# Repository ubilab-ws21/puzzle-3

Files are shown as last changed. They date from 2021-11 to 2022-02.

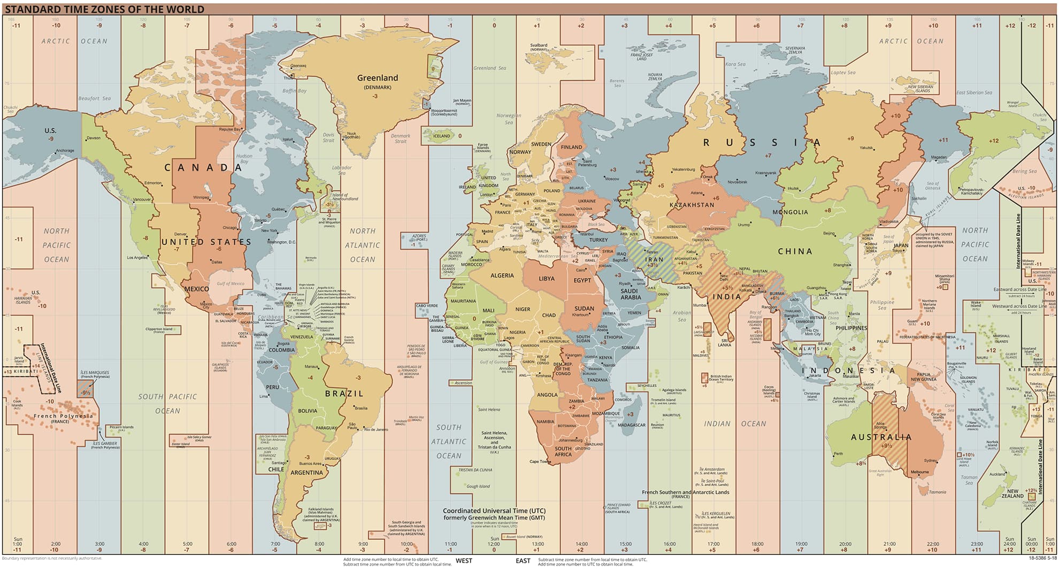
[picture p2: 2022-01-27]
designs/weltkarte-mit-zeitzonen-lg.jpg

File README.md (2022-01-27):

# Puzzle 3

## Contents
- [Puzzle overview](#puzzle-overview)
- [Repo Structure](#repo-structure)
- [Fitting the Puzzle into the story](#fitting-the-puzzle)
- [Puzzle description](#puzzle-description)
	- [Puzzle Part 1](#Puzzle-1)
	- [Puzzle Part 2](#Puzzle-2)
	- [Puzzle Part 3](#Puzzle-3)
- [MQTT Topics/Specification](#MQTT-Spec)
- [Documents](#documents)

## Puzzle overview

The central role of our puzzle plays a "radio".
The radio consists of a touchscreen display, a speaker, a module to play sound from an sd card, three encoders for tuning as well as one for the volume. The devices are all connected to a ESP32 WROOM Development kit. 
Final aim of the puzzle is to retrieve the so-called "green code" which is needed in a combination to restart the final server, i.e. to succeed in playining the Escape Room. 
It is to be discussed if the radio will maybe deliver more information, e.g. hints for the next puzzle (Morse-Code sound to open the server room door). 
The green code will eventually be displayed on the radio screen, once all the radio-related puzzles have been solved. The puzzles to be solved include the correct positioning of the three encoders which results in a change of the radio station.
The new channel also comes with a new radio display screen. Solving a word game now leads to the final green code. 

## Repo Structure

This repository is structured in the following way:
- datasheets contains all interesting datasheets
- designs contains eagle designs
- code contains the code
- notes cotains all notes from lectures and meetings

## Fitting the Puzzle into the story

The radio belongs to the hobby funker and former power distribution worker Ferdi. 
He has been fired a few years ago due to automatisation and digitalization of the distribution center. Ever since he has been fired, the work in the control room had been done autonomously. Ferdi has always predicted that the full autonoumous room can be dangerous in the future because nobody knows how to fix things if something goes wrong. 

## Puzzle Description 

### Puzzle Part 1 

There is an antenna hidden in the room. When the radio turns on, there is nothing but noise to hear. The players need to find the antenna and plug it into a socket one can find at the radio. This will trigger a button. Also, the correct positioning of the antenna makes a difference which is observed by an encoder insider the radio case. When both is fine, there will be no noise anymore and an emergency broadcast can be heard nicely.

### Puzzle Part 2
A world map is placed in the room. There are three colored pins placed on three diffeents countries pinned on the map. Meanwhile, the screen of the radio shows a three slider bars in the same colors, where the values of each bar can be changed with a correspondingly colored encoder.
Both the radio and the world map belong to the former control room worker, i.e. his name is printed on both the radio case and the world map.
The emergency broadcast plays repeatedly. 
The players must look at the pins on the map, extract the difference of the locations to the greenwich mean time (=delta) and turn the correspondingly colored encoders so that the sliding bars have the deltas as values. When this is done, the Emergency broadcast stops, and instead the voice of the former control room worker, a hobby radio operator, arises. Also the screen changed. The puzzle is solved.

### Puzzle Part 3
In the recording, the former control room worker repeatedly says that he has forseen this and that going away from manual control to autonoumously controlled distribution was a bad choice. 
The screen shows a word puzzle, where it is not clear yet how it looks exactly. From the voice from the radio guy it becomes clear how to solve the puzzle.
After the puzzle was solved, the screen changes again and shows the code which is needed for the next puzzle of the next group (code for opening the door via light bulbs)

## MQTT Topics/Specification

| Topic | Description | Payload | Reset-Value | Subscriber | Publisher |
| :--:	| :---: | :---:| :---: |:---: | :---:|
| 3/gamecontrol| Control the radio: which puzzle state is currently in play | Enum(Gamecontrol) | idle | radio, operator | radio, operator | 
| 3/antenna/orientation | gives information if the angle of the antenna correct | boolean | false | operator | radio |
| 3/map/knob1 | gives information whether knob1 is in correct position | boolean | false | operator | radio |
| 3/map/knob2 | gives information whether knob2 is in correct position | boolean | false | operator | radio |
| 3/map/knob3 | gives information whether knob3 is in correct position | boolean | false | operator | radio |
| 3/touchgame/trialCount | gives information about the trails the group already had | int | 0 | operator | radio |
| 3/touchgame/displayTime | the game can either be set in easy or hard mode | boolean | false | radio | operator |

3/gamecontrol maybe splitted to received and sended topic. For now we wait for feedback by the operator

| Enum(gameControl) | Description | Subscriber | Publisher |
| :---: | :---: | :---: | :---: |
| idle | Radiopuzzle is waiting in idle mode to be started by operator | radio | operator |
| antenna | antenna game is started by operator | radio | operator |
| antennaFinished | antenna game is finished | operator | radio |
| map | map game is started by operator | radio | operator |
| mapFinished | map game is finished | operator | radio |
| touchgame | touchgame is started by operator | radio | operator |
| touchgameFinished | touchgame is finished | operator | radio |
| finished | radio game is finished | operator | radio |

| int(trailCount) | Description |
| :---: | :---: |
| ++ | everytime the game is failed, the trialcounter is increased |

#Topic: 3/gamecontrol

Description: Control the radio: which puzzle state is currently in play

Payload: Enum(Gamecontrol)

Reset-Value: Idle

Enum Values:

# Idle: Radio puzzle is waiting in Idle mode to be started
- Publisher: Operator: set the third puzzle in idle mode
- Subscriber: Radio: receive to stay in idle mode

- antenna: antenna game is started
	Operator: start the first part of the puzzle
	radio: receive to start the puzzle with antenna game
- antennaFinished: antenna game is finished
	Operator: receive updates on the gamestatus
	radio: update once the game is finished

- map: map game is played
	Operator: start the second part of the puzzle
	radio: receive to start the second part of the puzzle
- mapFinished: map game is finished
	Operator: receive updates on the gamestatus
	radio: update once the game is finished

- touchgame: touchgame is played
	Operator: start the third part of the puzzle
	radio: receive to start the third part of the puzzle
- touchgameFinished: touchgame is finished
	Operator: receive updates on the game status
	radio: update once the game is finished

- finished: puzzle 3 is solved
	Operator: set the third puzzle in finished mode
	radio: receive to get in finished mode

<!--Topic: 3/antenna/plugStatus

#Description: gives information about the antenna

% Payload: boolean

Reset-Value: false
	Radio: update if antenna is plugged in
	Operator: receive updates on the antenna-->
	
Topic: 3/antenna/orientation

Description: gives information about the antenna orientation, should the operator know about the randomisation of the required postion?

Payload: int[0-23] or boolean
	Radio: update if antenna is set up in the correct direction
	Operator: receive updates on the antenna orientation

Topic: 3/map/knob1

Description: Control/Check the first knob

Playload: boolean

Reset-Value: false
	Radio: update if the the first knob/color reaches/leaves the correct postion
	Operator: receive updates on the first knob

Topic: 3/map/knob2

Description: Control/Check the second knob

Playload: boolean

Reset-Value: false
	Radio: update if the the second knob/color reaches/leaves the correct postion
	Operator: receive updates on the second knob

Topic: 3/map/knob3

Description: Control/Check the third knob

Playload: boolean

Reset-Value: false
	Radio: update if the the third knob/color reaches/leaves the correct postion
	Operator: receive updates on the third knob

Topic: 3/touchgame/trialCount

Description: Sends the number of trials to the operator 

Payload: int

Reset-Value is 0
	Radio: Update the trial number after each failed attempt
	Operator: receive updates on the failed attempts
	
Topic: 3/touchgame/displayTime

Description: Operator sets the time to easy or hard mode

Payload: boolean

Reset-Value: false
	Radio: receive updates on mode setting
	Operator: set mode for puzzle

Description: needs some discussion what should be updated to the operator

## Documents
The datasheets can be found in the datasheets directory

## Notes
The board with the ICs, placed on the bottom of the radio case inside, should be 9cm x 13cm long.
Software game: We only have one rectangle. By placing the blue rectangle on a letter and touching it, the rectangle and the letter will go to the next free location in the password space.

Next Tasks - 23.01
- Driver Board an case anbringen
- MQTT auf ESP32 fertig implementieren

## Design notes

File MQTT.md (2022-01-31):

The MQQT-Specification for Puzzle 3:

| Topic | Description | Payload | Reset-Value | Subscriber | Publisher |
| :--:	| :---: | :---:| :---: |:---: | :---:|
| 3/gamecontrol/antenna| Control the radio: start first puzzle & receive updates on it | on & off, inactive, active & solved | off | radio, operator | radio, operator | 
| 3/gamecontrol/map | Control the radio: start the second puzzle & receive updates on it | on & off, inactive, active & solved | off | operator, radio | radio, operator |
| 3/gamecontrol/touchgame | Control the radio: start the third puzzle & receive updates on it | on & off, inactive, active & solved | off | operator, radio | radio, operator |
| 3/audiocontrol/roomsolved | Control the radio: play final message when the room is solved | on & off | off | radio | operator |

We reduced the amount of MQTT-Topics since the hint-system is controlled by us directly: Therefore it is not required to send all informations to the operator, which are not really helpful in terms of gamecontrol.

MQTT-Topics for the hint-system
| Topic | Description | Payload | Reset-Value | Subscriber | Publisher |
| :--:	| :---: | :---:| :---: |:---: | :---:|
| game/puzzle3/antenna | Hint-System: Unlock the hint for the first game | active_1 & inactive | inactive | hint-system | radio |
| game/puzzle3/map | Hint-System: Unlock the hints for the second game | active_1, active_2 & inactive | inactive | hint-system | radio |
| game/puzzle3/touchgame | Hint-System: Unlock the hints for the third game | active_1, active_2, active_3, active_4 & inactive | inactive | hint-system | radio |

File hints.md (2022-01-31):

### Hints to be display for Puzzle 3 including the MQTT-Spec

## Game 1: Antenna
Hint 1: What do you do if a radio does have a bad connection?
MQTT-Message: game/puzzle3/antenna : {"method": "trigger", "state": "active_1"}

## Game 2: Map
Hint 1: The room operator usually spend his holiday at three locations
MQTT-Message: game/puzzle3/map : {"method": "trigger", "state": "active_1"}

Hint 2: These locations are in different time zones
MQTT-Message: game/puzzle3/map : {"method": "trigger", "state": "active_2"}

## Game 3: Touchgame
Hint 1: Touch the letters to build a word.
MQTT-Message: game/puzzle3/touchgame : {"method": "trigger", "state": "active_1"}

Hint 2: Listen carefully.
MQTT-Message: game/puzzle3/touchgame : {"method": "trigger", "state": "active_2"}

Hint 3: Not automatic.
MQTT-Message: game/puzzle3/touchgame : {"method": "trigger", "state": "active_3"}

Hint 4: Manual.
MQTT-Message: game/puzzle3/touchgame : {"method": "trigger", "state": "active_4"}

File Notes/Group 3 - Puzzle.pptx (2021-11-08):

## Group 3

Puzzle

## Puzzle 3 Idea 2

- Radio plays news/emergency broadcast
  - Starts when emergency electricity is back on (or by solving another puzzle)
  - A sound/jingle is playing in the background or as a intro – repeated
  - Sound code is key to ??? – safe/door/etc. (buttons play same tone/sound)
- A received code will lead to a hidden radio station – every other station will play the standard
- Unknown person (aluhat guy/hobby radio operator) tells crazy story that leads to information for next puzzle

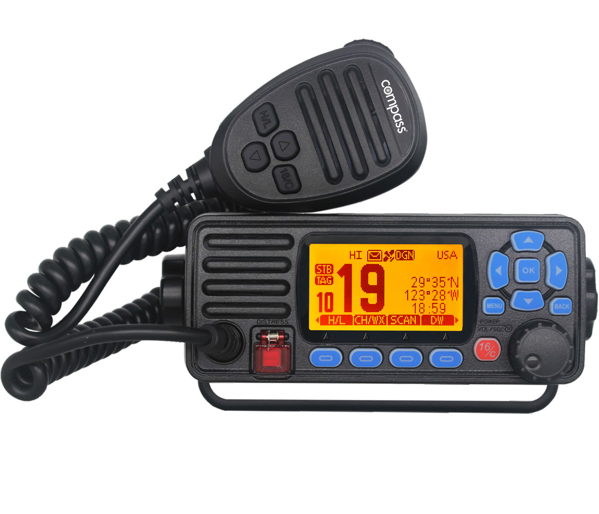
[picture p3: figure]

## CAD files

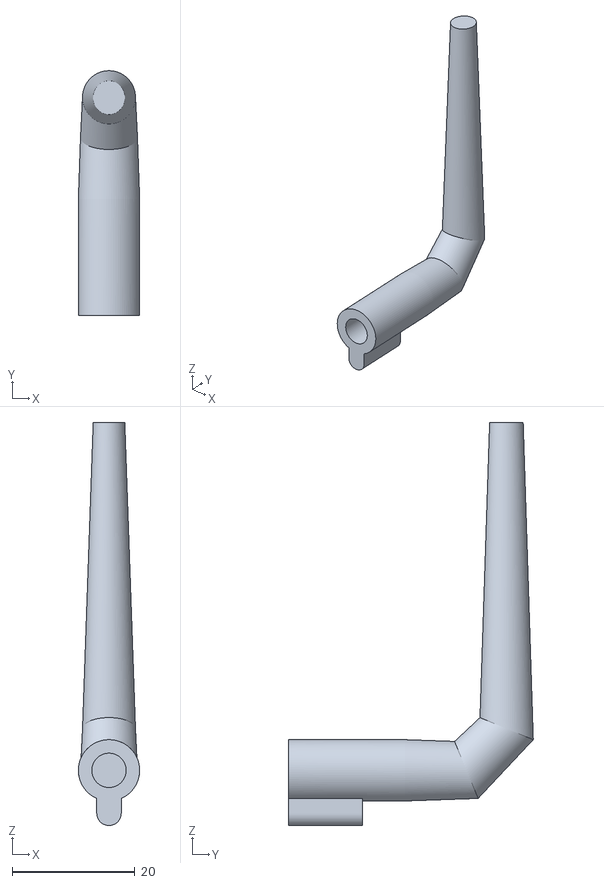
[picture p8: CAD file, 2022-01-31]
designs/3D_Manufactoring/Antenna.stl
10.00 x 39.9 x 65.7

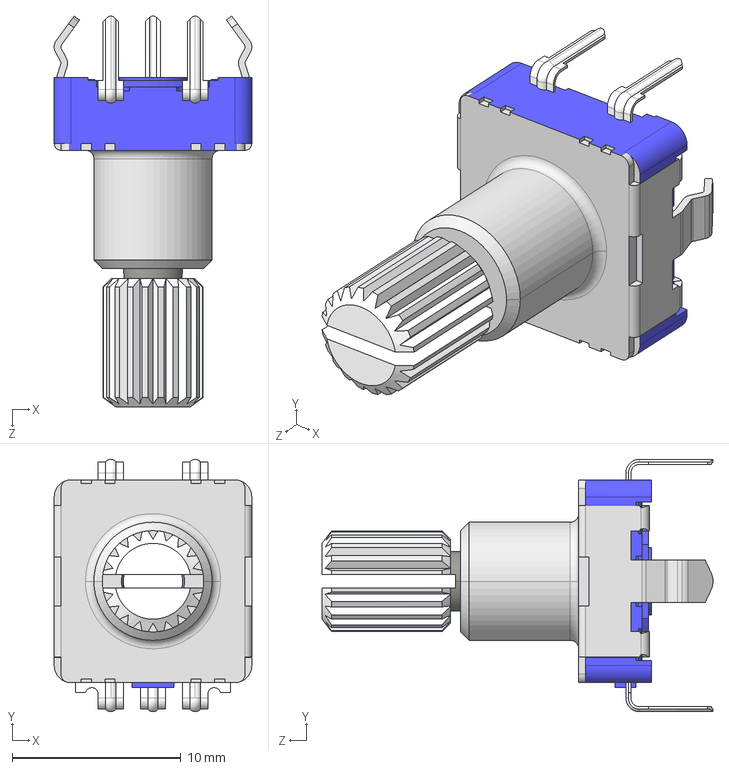
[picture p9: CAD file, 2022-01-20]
designs/3D_Modeling/ec11_rotarary_encoder/EC11 Rotary Encoder Dode Switch-15mm .STEP
11.7 x 15.0 x 23.2 mm

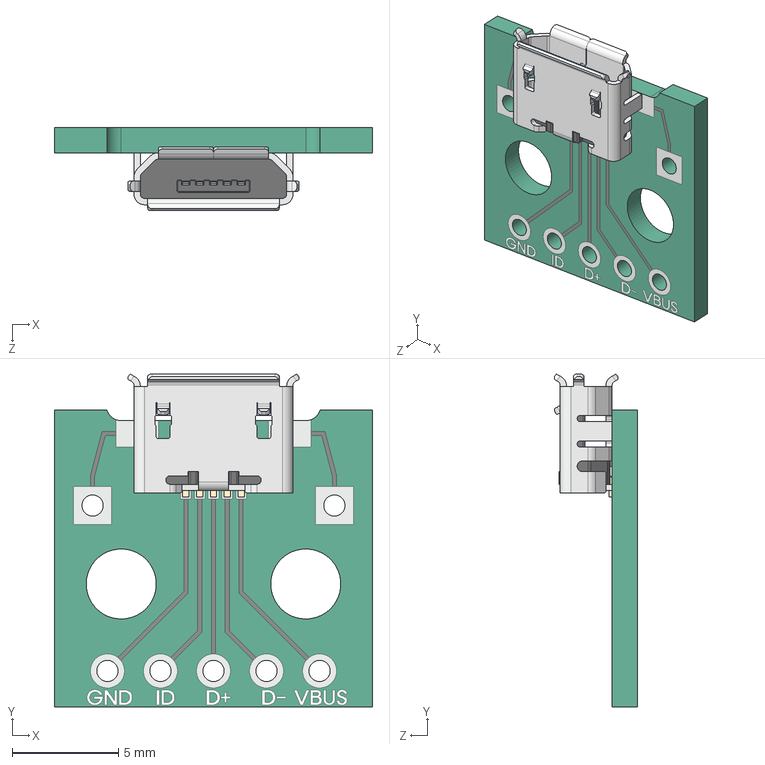
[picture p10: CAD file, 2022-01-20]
designs/3D_Modeling/microusb_5pin/REAL-Usb 5pin Board.STEP
15.0 x 15.7 x 3.92 mm

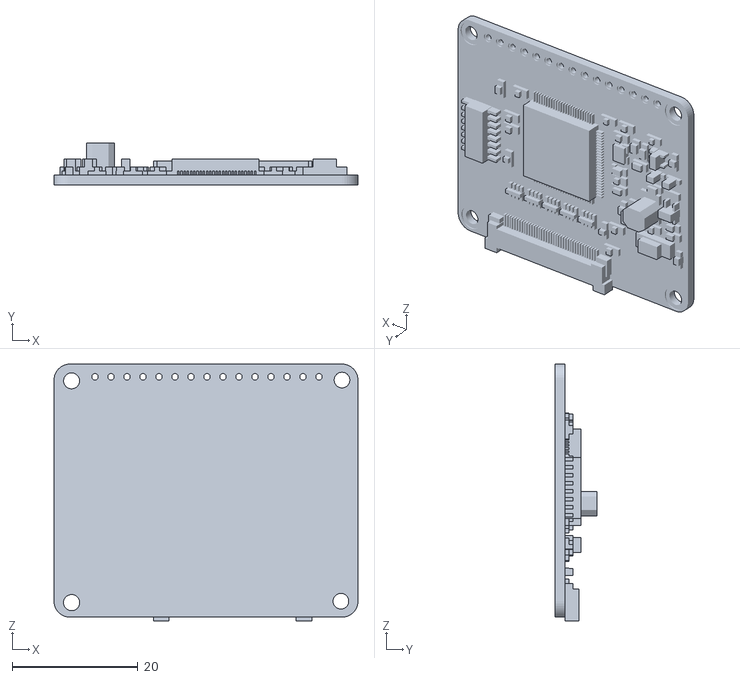
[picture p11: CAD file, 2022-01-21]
designs/3D_Modeling/RA8875 Driver Board.STL
48.3 x 6.68 x 40.8

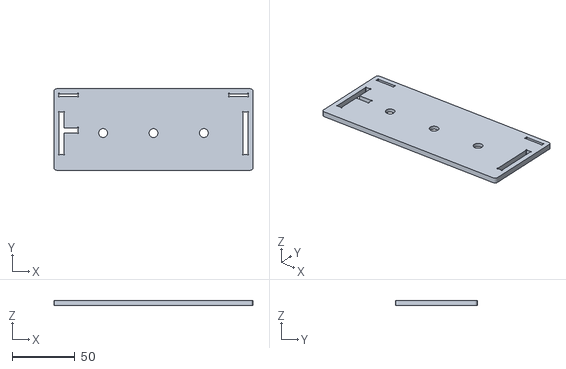
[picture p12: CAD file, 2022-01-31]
designs/3D_Manufactoring/topPlate_3DPrint.stl
158.0 x 64.7 x 4.00

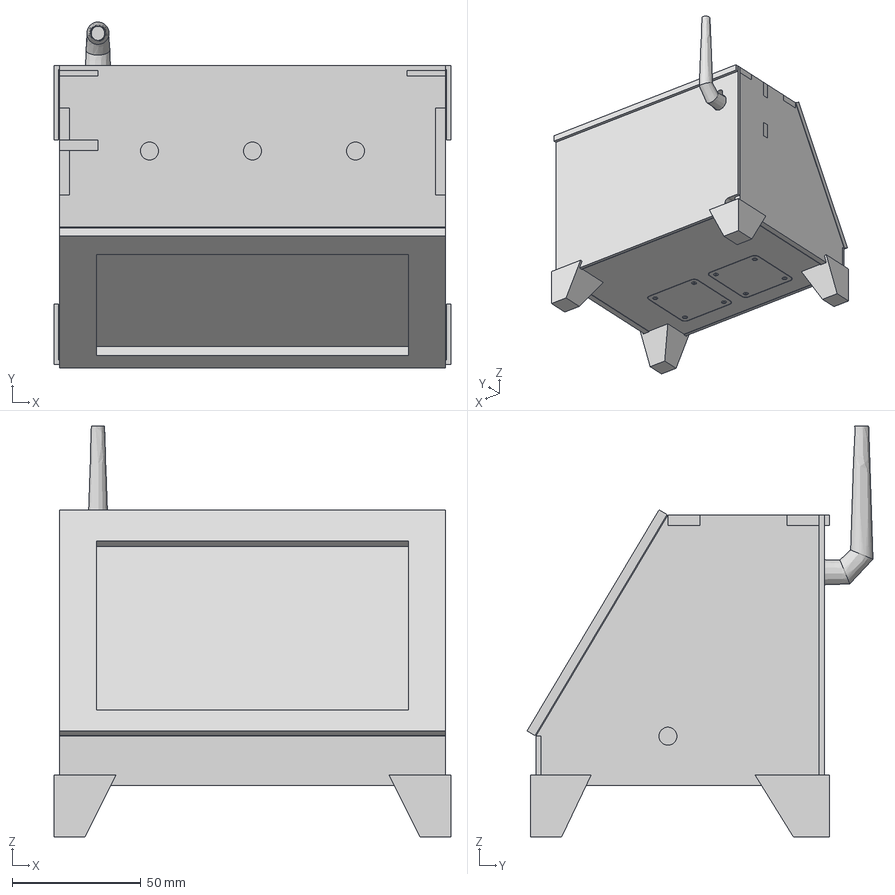
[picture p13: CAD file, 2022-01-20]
designs/3D_Modeling/Radio.step
154.0 x 134.3 x 159.6 mm
Speaker v3
Antenna_3D
EC11 Rotary Encoder Dode Switch-15mm
groundPlate_3D
rightPlate_laser
leftPlate_laser
frontPlate_CNC
backPlate_CNC
topPlate_laser
Component_Display
REAL-Usb 5pin Board

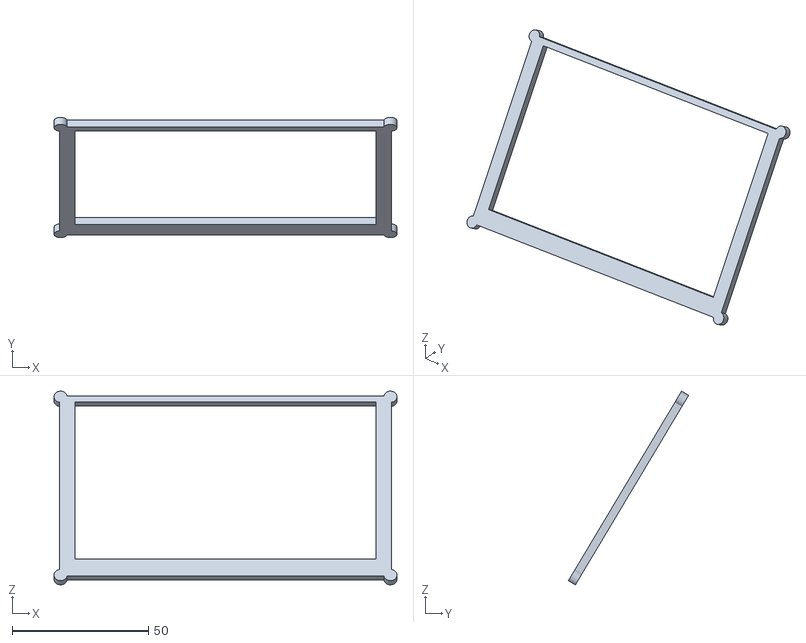
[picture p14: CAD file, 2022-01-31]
designs/3D_Manufactoring/DisplayHousingTop.stl
126.0 x 44.2 x 71.2

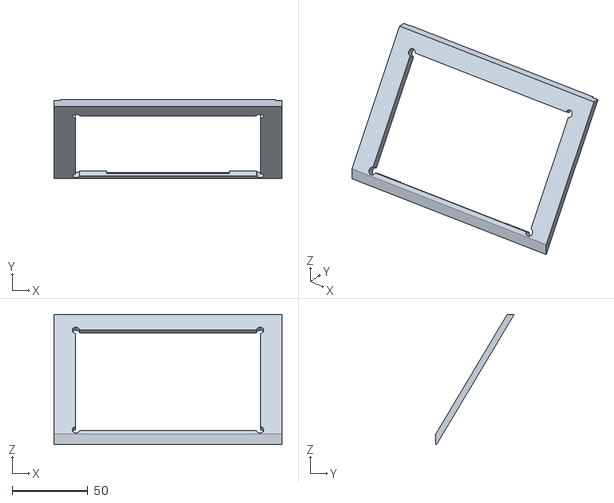
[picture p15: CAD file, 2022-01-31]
designs/3D_Manufactoring/DisplayHousingButtomTEST.stl
150.0 x 51.7 x 85.9

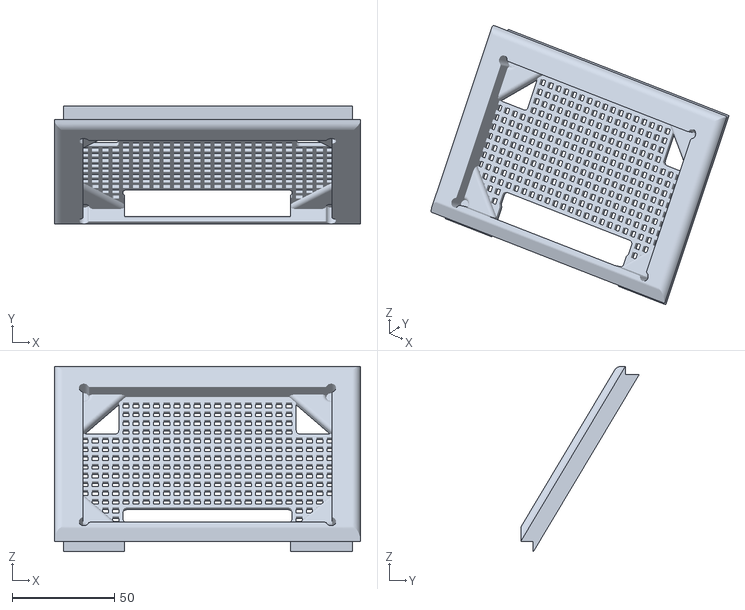
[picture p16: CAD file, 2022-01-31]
designs/3D_Manufactoring/DisplayHousingButtom.stl
150.0 x 58.1 x 90.9

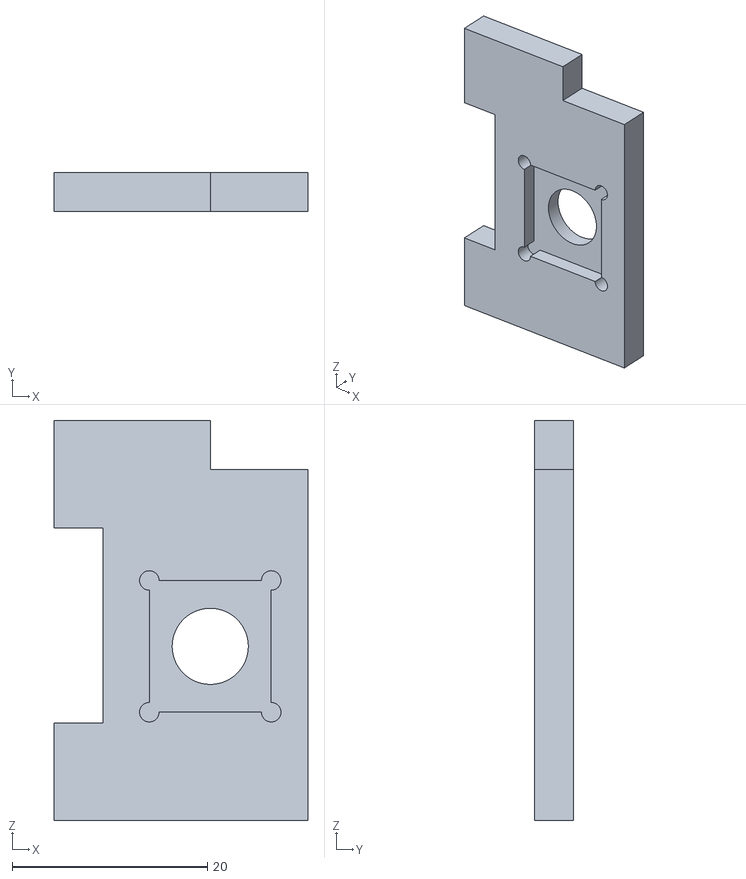
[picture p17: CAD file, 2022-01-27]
designs/3D_Manufactoring/antennaSupport_3DprintV3.stl
26.0 x 4.00 x 41.0

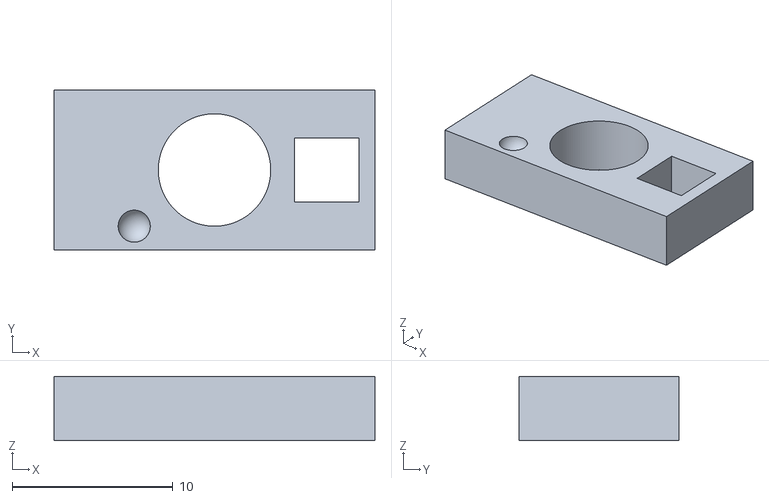
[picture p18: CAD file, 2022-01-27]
designs/3D_Manufactoring/smallTestPrint.stl
20.0 x 10.0 x 4.00

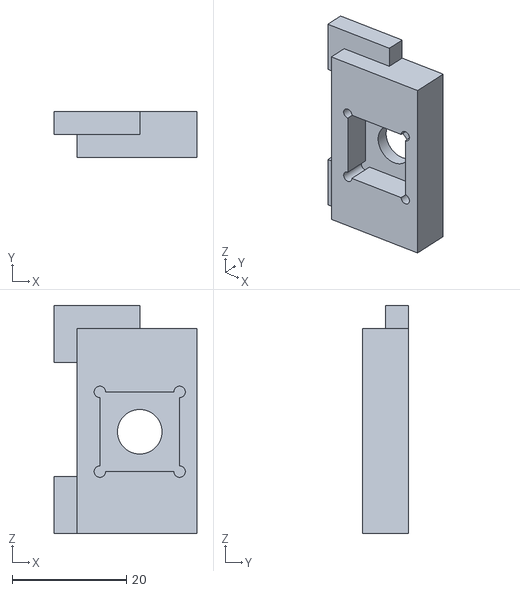
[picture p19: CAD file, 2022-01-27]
designs/3D_Manufactoring/antennaSupport_3Dprint.stl
25.0 x 8.00 x 40.0

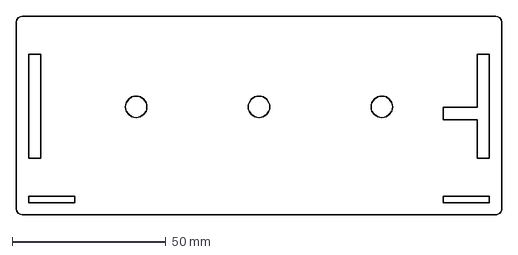
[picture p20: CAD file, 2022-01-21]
designs/3D_Manufactoring/topPlate.dxf
158.0 x 64.7 mm

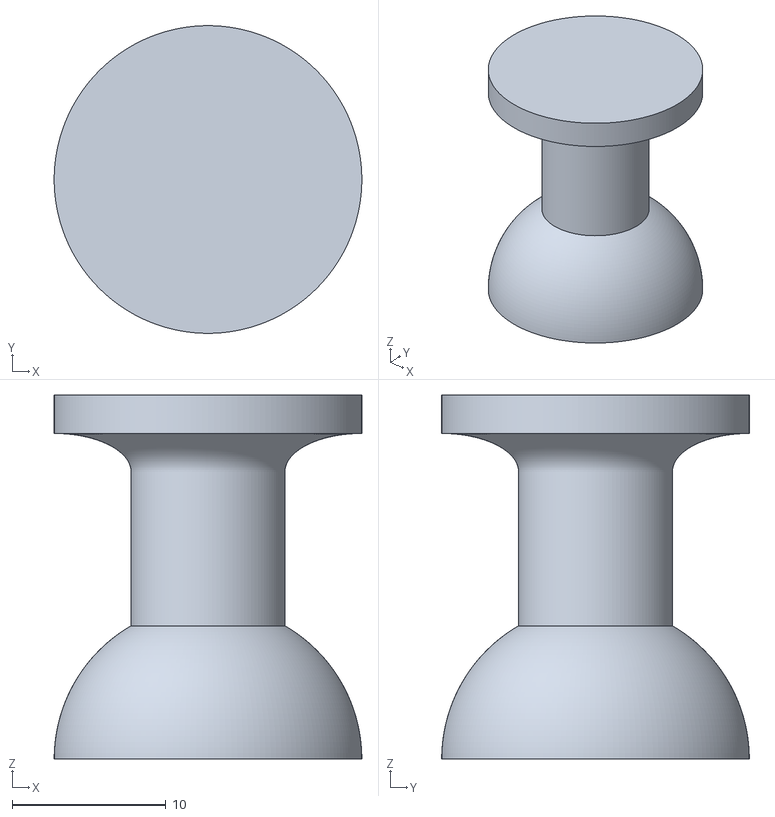
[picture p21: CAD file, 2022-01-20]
designs/3D_Manufactoring/EncoderPinHead.stl
20.0 x 20.0 x 23.7

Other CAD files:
designs/3D_Manufactoring/leftPlate.dxf
designs/3D_Manufactoring/groundPlate.stl
designs/3D_Manufactoring/DisplayCircuitMount.stl
designs/3D_Manufactoring/antennaSupport.dxf
designs/3D_Manufactoring/antennaSupport_3DprintV2.stl
designs/3D_Manufactoring/antennaSupport_3Dprint_v1.stl
designs/3D_Manufactoring/rightPlate.dxf
designs/3D_Modeling/microusb_5pin/REAL-Usb 5pin Board.SLDPRT
designs/3D_Modeling/microusb_5pin/REAL-Usb 5pin Board.x_t

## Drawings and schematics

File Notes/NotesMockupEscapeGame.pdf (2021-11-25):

Notes | Tiah | Play | Escape Roon | 25.1120µV
- | Radio will | provider | 2 codes ?

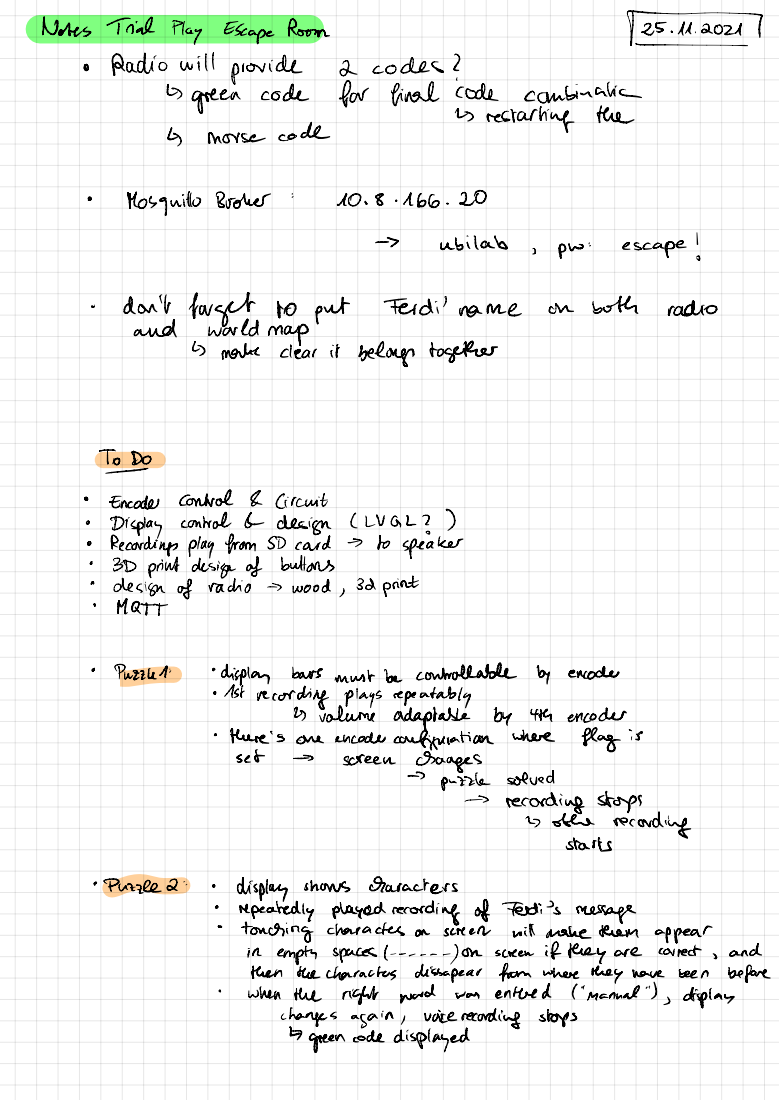
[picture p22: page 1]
green; code; for; final; Code; combination; resrartinf; the; Morsecode; Mosquito; Bücher; ubilab; escape !; don't; fwgct; put; Ferdi ' name; both; radio; and; world map ↳; make; Hear it; belong; together; Toto; Encoder; Conhrol; Circuit; Display; antrat &; design; LVGL; Recordings; play from SD; card; speaker •; print; design of; buttons; wood; print •; MQTT; Puzzle1:; display; bavs.mustbecontrollabll.by; encoder; recording; plays repeatablg; volume; adaptable; 4th encoder; there's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

green code displaced

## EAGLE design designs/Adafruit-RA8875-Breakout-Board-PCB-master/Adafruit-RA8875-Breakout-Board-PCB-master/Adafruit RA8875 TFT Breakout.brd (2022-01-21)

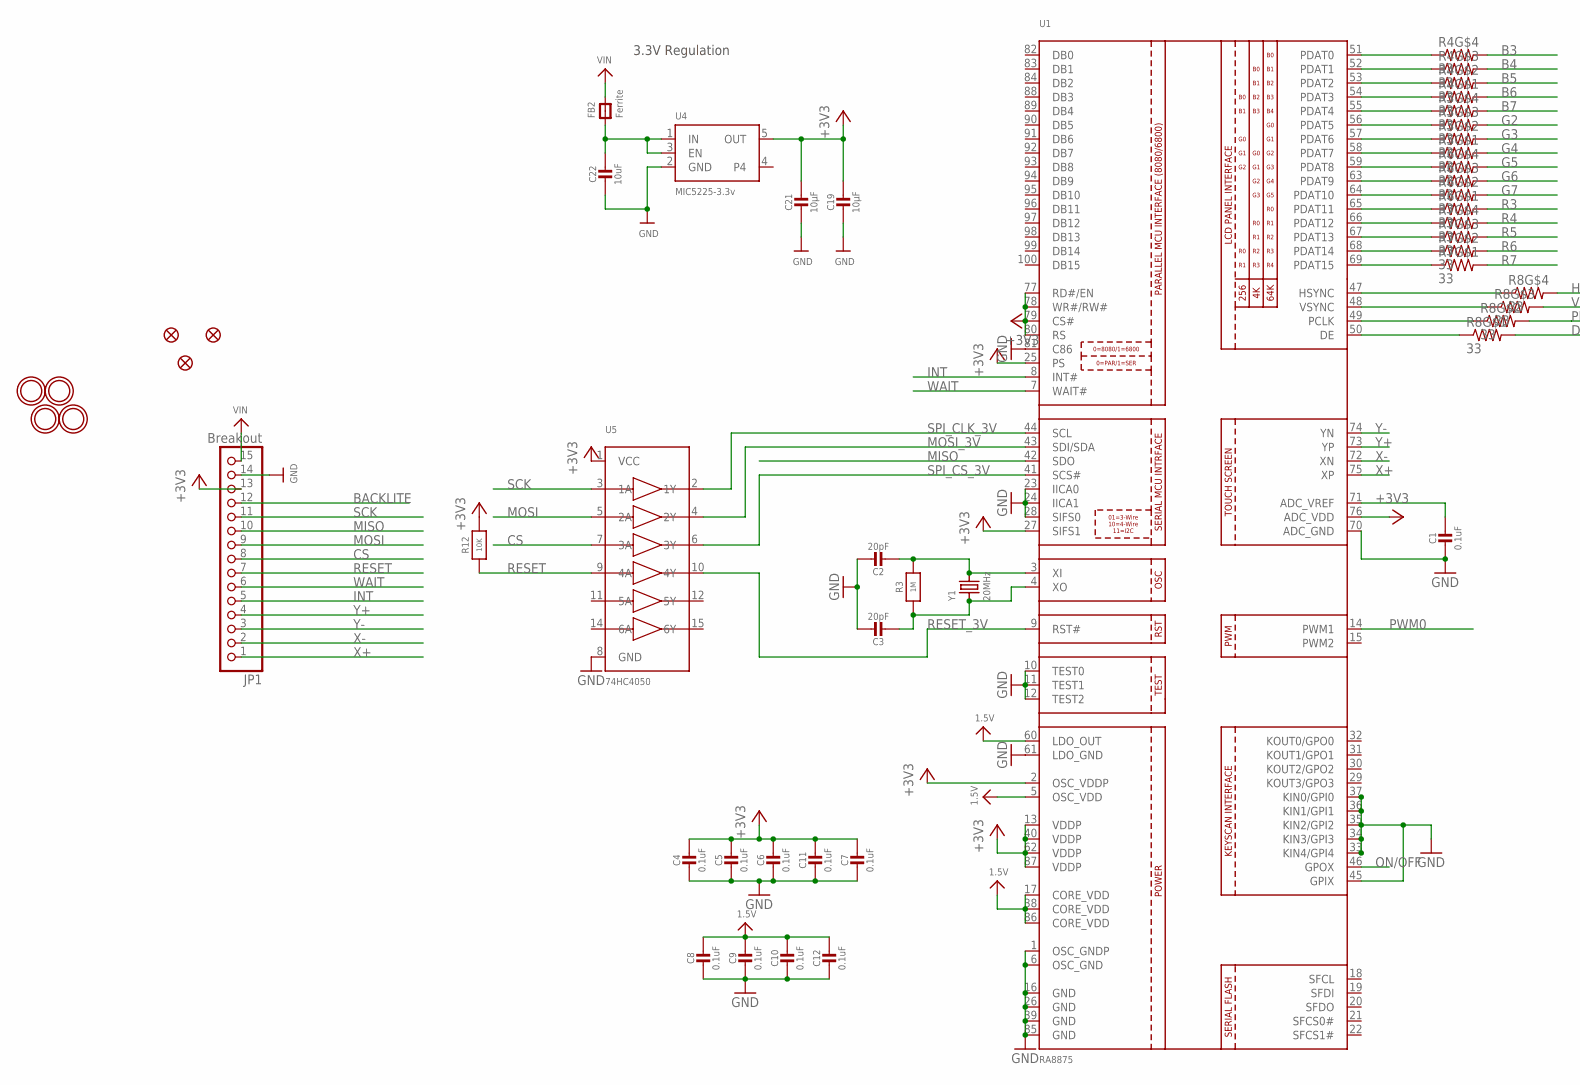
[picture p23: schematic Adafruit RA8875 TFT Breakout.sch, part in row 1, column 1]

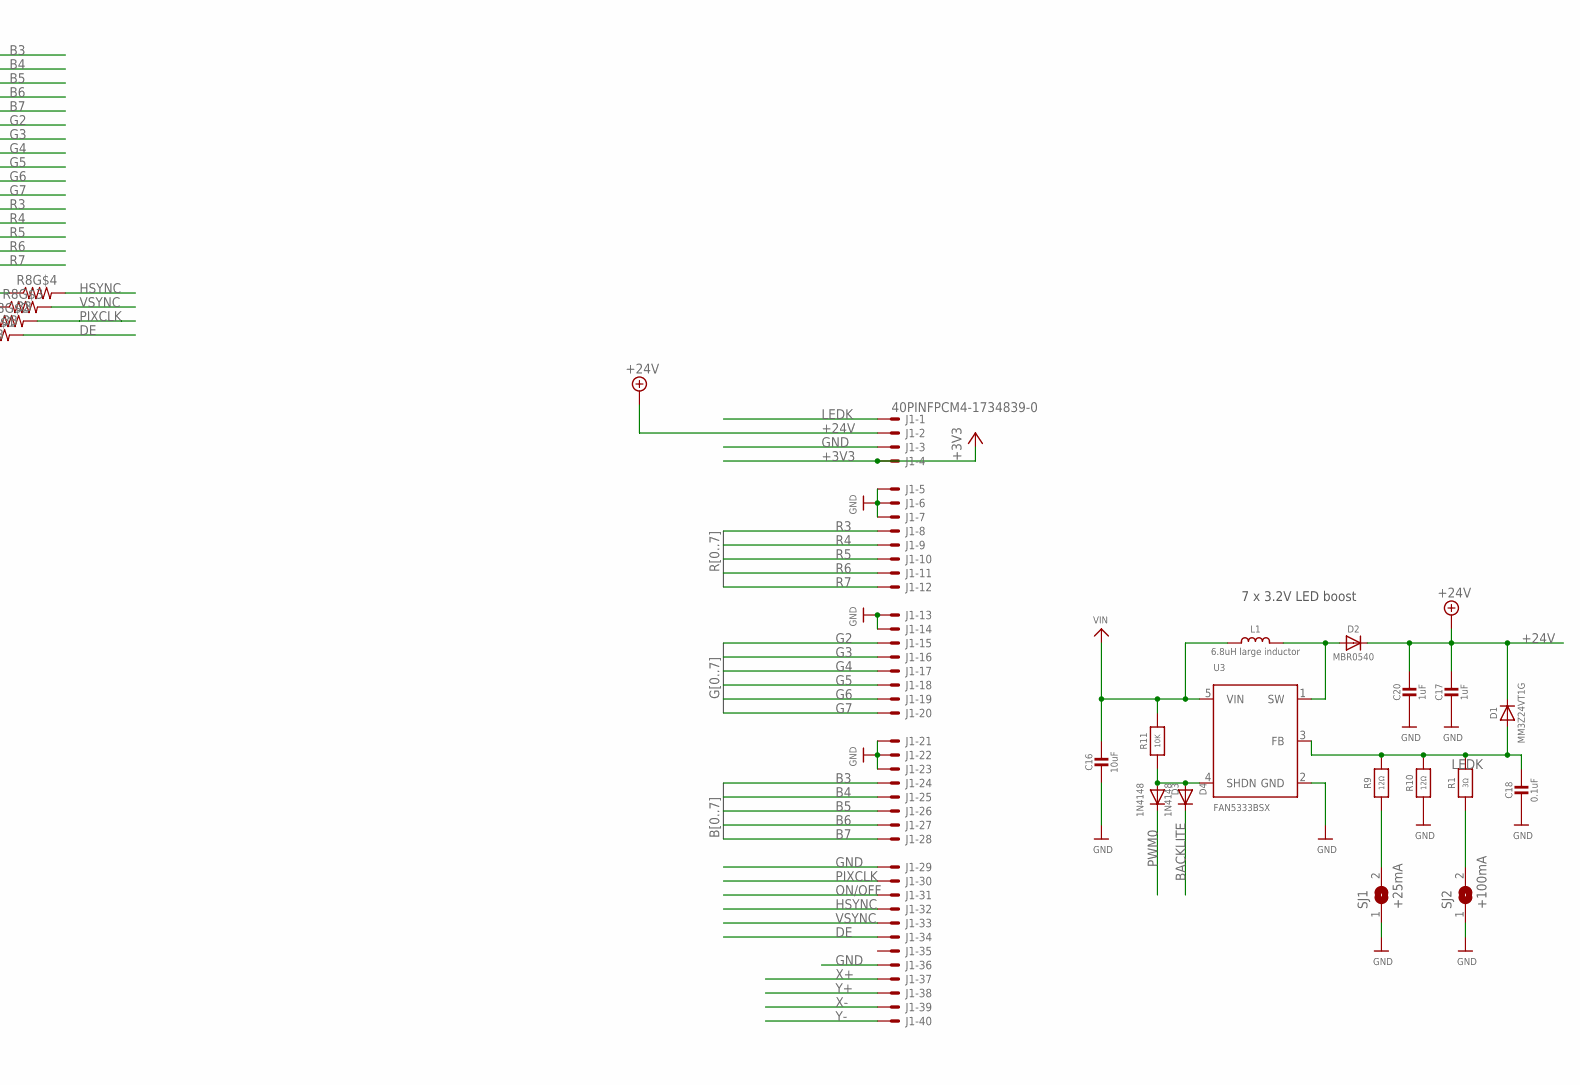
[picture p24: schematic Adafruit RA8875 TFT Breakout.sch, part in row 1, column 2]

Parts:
C1, C4, C5, C6, C7, C8, C9, C10, C11, C12: 0.1uF; 0805-NO
C2, C3: 20pF; 0805-NO
C16, C22: 10uF; _0805MP
C17, C20: 1uF; _0805MP
C18: 0.1uF; _0805MP
C19, C21: 10µF; _0805MP
D1: MM3Z24VT1G; SMADIODE
D2: MBR0540; SOD-123
D3, D4: 1N4148; SOD-323F
FB2: Ferrite; _0805MP
FID1, FID2, FID3: FIDUCIAL""; FIDUCIAL_1MM
J1: 40PINFPCM4-1734839-0; 4-1734839-0
JP1: Breakout; 1X15-CB
L1: 6.8uH large inductor; INDUCTOR_5X5MM_NR5040_NOTHERMALS
R1: 3Ω; _0805MP
R3: 1M; 0805-NO
R4, R5, R6, R7, R8: 33; RESPACK_4X0603
R9, R10: 12Ω; _0805MP
R11: 10K; _0805MP
R12: 10K; 0805-NO
SJ1: +25mA; SOLDERJUMPER_ARROW_NOPASTE
SJ2: +100mA; SOLDERJUMPER_ARROW_NOPASTE
U1: RA8875; LQFP100
U3: FAN5333BSX; SOT23-5@1
U4: MIC5225-3.3v; SOT23-5
U5: 74HC4050; SOIC16
U$21, U$22, U$23, U$24: MOUNTINGHOLE2.5; MOUNTINGHOLE_2.5_PLATED
Y1: 20MHz; CRYSTAL_3.2X2.5

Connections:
1.5V: C8.1, C9.1, C10.1, C12.1, U1.5 (OSC_VDD), U1.17 (CORE_VDD), U1.38 (CORE_VDD), U1.60 (LDO_OUT), U1.86 (CORE_VDD)
+3V3: C4.1, C5.1, C6.1, C7.1, C11.1, C19.1, C21.1, J1.4 (MS), JP1.13, R12.2, U1.2 (OSC_VDDP), U1.13 (VDDP), U1.25 (PS), U1.27 (SIFS1), U1.40 (VDDP), U1.62 (VDDP), U1.76 (ADC_VDD), U1.77 (RD#/EN), U1.78 (WR#/RW#), U1.79 (CS#), U1.80 (RS), U1.87 (VDDP), U4.5 (OUT), U5.1 (VCC)
+24V: C17.1, C20.1, D1.C, D2.C, J1.2 (MS)
B3: J1.24 (MS), R4.5 (2)
B4: J1.25 (MS), R4.6 (2)
B5: J1.26 (MS), R4.7 (2)
B6: J1.27 (MS), R4.8 (2)
B7: J1.28 (MS), R5.5 (2)
BACKLITE: D4.C, JP1.12
CS: JP1.8, U5.7 (3A)
DE: J1.34 (MS), R8.8 (2)
G2: J1.15 (MS), R5.6 (2)
G3: J1.16 (MS), R5.7 (2)
G4: J1.17 (MS), R5.8 (2)
G5: J1.18 (MS), R6.5 (2)
G6: J1.19 (MS), R6.6 (2)
G7: J1.20 (MS), R6.7 (2)
GND: C1.2, C2.1, C3.1, C4.2, C5.2, C6.2, C7.2, C8.2, C9.2, C10.2, C11.2, C12.2, C16.2, C17.2, C18.2, C19.2, C20.2, C21.2, C22.2, J1.3 (MS), J1.5 (MS), J1.6 (MS), J1.7 (MS), J1.13 (MS), J1.14 (MS), J1.21 (MS), J1.22 (MS), J1.23 (MS), J1.29 (MS), J1.36 (MS), JP1.14, R10.1, SJ1.1, SJ2.1, U1.1 (OSC_GNDP), U1.6 (OSC_GND), U1.10 (TEST0), U1.11 (TEST1), U1.12 (TEST2), U1.16 (GND), U1.23 (IICA0), U1.24 (IICA1), U1.26 (GND), U1.28 (SIFS0), U1.33 (KIN4/GPI4), U1.34 (KIN3/GPI3), U1.35 (KIN2/GPI2), U1.36 (KIN1/GPI1), U1.37 (KIN0/GPI0), U1.39 (GND), U1.45 (GPIX), U1.61 (LDO_GND), U1.70 (ADC_GND), U1.81 (C86), U1.85 (GND), U3.2 (GND), U4.2 (GND), U5.8 (GND)
HSYNC: J1.32 (MS), R8.5 (2)
INT: JP1.5, U1.8 (INT#)
LEDK: C18.1, D1.A, J1.1 (MSV), R1.2, R9.2, R10.2, U3.3 (FB)
MISO: JP1.10, U1.42 (SDO)
MOSI: JP1.9, U5.5 (2A)
MOSI_3V: U1.43 (SDI/SDA), U5.4 (2Y)
unnamed: D2.A, L1.P$2 (2), U3.1 (SW)
unnamed: C2.2, R3.2, U1.3 (XI), Y1.2
unnamed: C1.1, U1.71 (ADC_VREF)
unnamed: R4.4 (1), U1.51 (PDAT0)
unnamed: R4.3 (1), U1.52 (PDAT1)
unnamed: R4.2 (1), U1.53 (PDAT2)
unnamed: R4.1, U1.54 (PDAT3)
unnamed: R5.4 (1), U1.55 (PDAT4)
unnamed: R5.3 (1), U1.56 (PDAT5)
unnamed: R5.2 (1), U1.57 (PDAT6)
unnamed: R5.1, U1.58 (PDAT7)
unnamed: R6.4 (1), U1.59 (PDAT8)
unnamed: R6.3 (1), U1.63 (PDAT9)
unnamed: R6.2 (1), U1.64 (PDAT10)
unnamed: R6.1, U1.65 (PDAT11)
unnamed: R7.4 (1), U1.66 (PDAT12)
unnamed: R7.3 (1), U1.67 (PDAT13)
unnamed: R7.2 (1), U1.68 (PDAT14)
unnamed: R7.1, U1.69 (PDAT15)
unnamed: R8.1, U1.50 (DE)
unnamed: R8.2 (1), U1.49 (PCLK)
unnamed: R8.3 (1), U1.48 (VSYNC)
unnamed: R8.4 (1), U1.47 (HSYNC)
unnamed: R9.1, SJ1.2
unnamed: C22.1, FB2.1, U4.1 (IN), U4.3 (EN)
unnamed: R1.1, SJ2.2
unnamed: C3.2, R3.1, U1.4 (XO), Y1.1
ON/OFF: J1.31 (MS), U1.46 (GPOX)
PIXCLK: J1.30 (MS), R8.7 (2)
PWM0: D3.C, U1.14 (PWM1)
R3: J1.8 (MS), R6.8 (2)
R4: J1.9 (MS), R7.5 (2)
R5: J1.10 (MS), R7.6 (2)
R6: J1.11 (MS), R7.7 (2)
R7: J1.12 (MS), R7.8 (2)
RESET: JP1.7, R12.1, U5.9 (4A)
RESET_3V: U1.9 (RST#), U5.10 (4Y)
SCK: JP1.11, U5.3 (1A)
SHDN: D3.A, D4.A, R11.1, U3.4 (SHDN)
SPI_CLK_3V: U1.44 (SCL), U5.2 (1Y)
SPI_CS_3V: U1.41 (SCS#), U5.6 (3Y)
VIN: C16.1, FB2.2, JP1.15, L1.P$1 (1), R11.2, U3.5 (VIN)
VSYNC: J1.33 (MS), R8.6 (2)
WAIT: JP1.6, U1.7 (WAIT#)
X+: J1.37 (MS), JP1.1, U1.75 (XP)
X-: J1.39 (MS), JP1.2, U1.72 (XN)
Y+: J1.38 (MS), JP1.4, U1.73 (YP)
Y-: J1.40 (MS), JP1.3, U1.74 (YN)

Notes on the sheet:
7 x 3.2V LED boost
3.3V Regulation

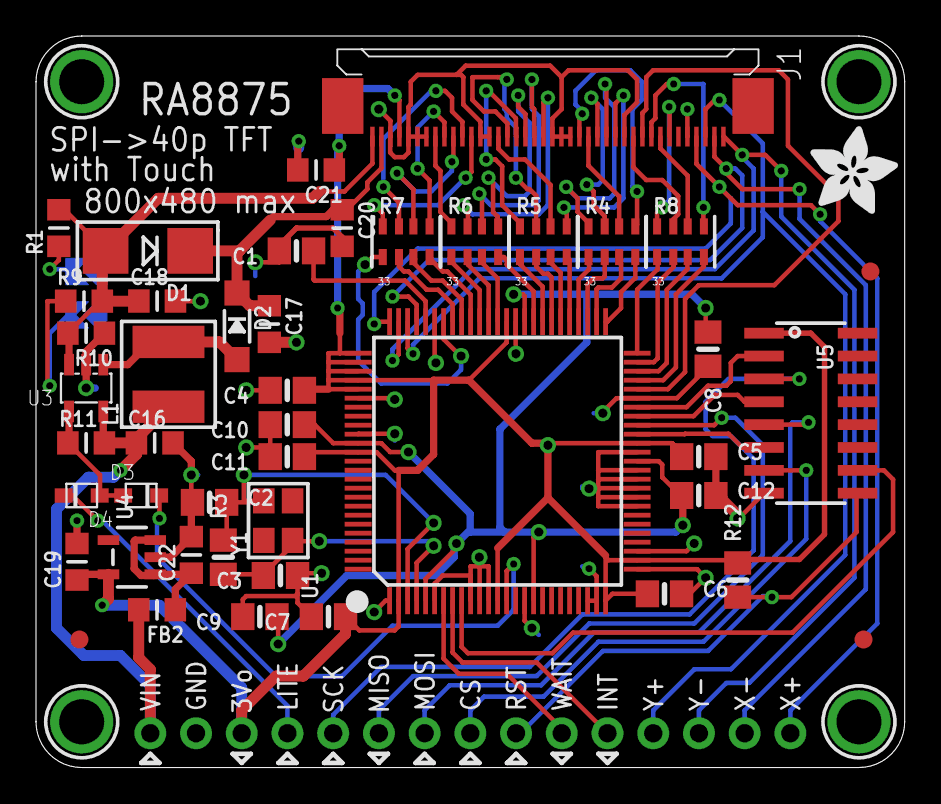
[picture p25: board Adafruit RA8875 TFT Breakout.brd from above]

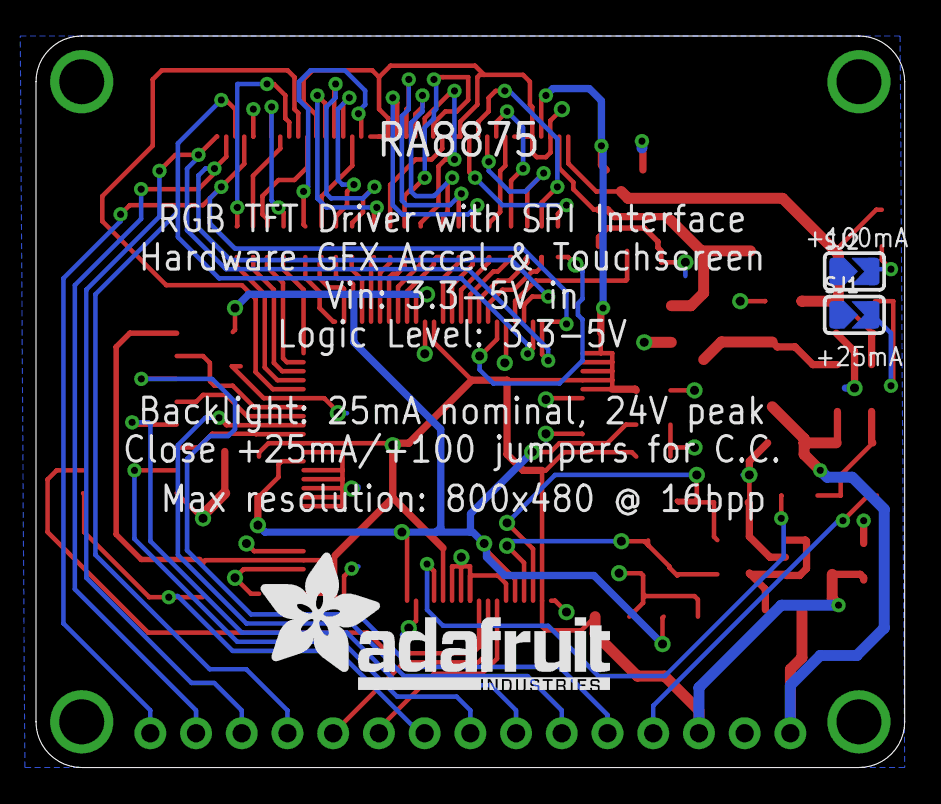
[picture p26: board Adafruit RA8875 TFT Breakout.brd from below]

Board: 2 copper layers, 48.3 x 40.6 mm, 54 parts (3 on the bottom side), 72 nets.

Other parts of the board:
U$18: ADAFRUIT_5MM
U$25: ADAFRUIT_TEXT_20MM

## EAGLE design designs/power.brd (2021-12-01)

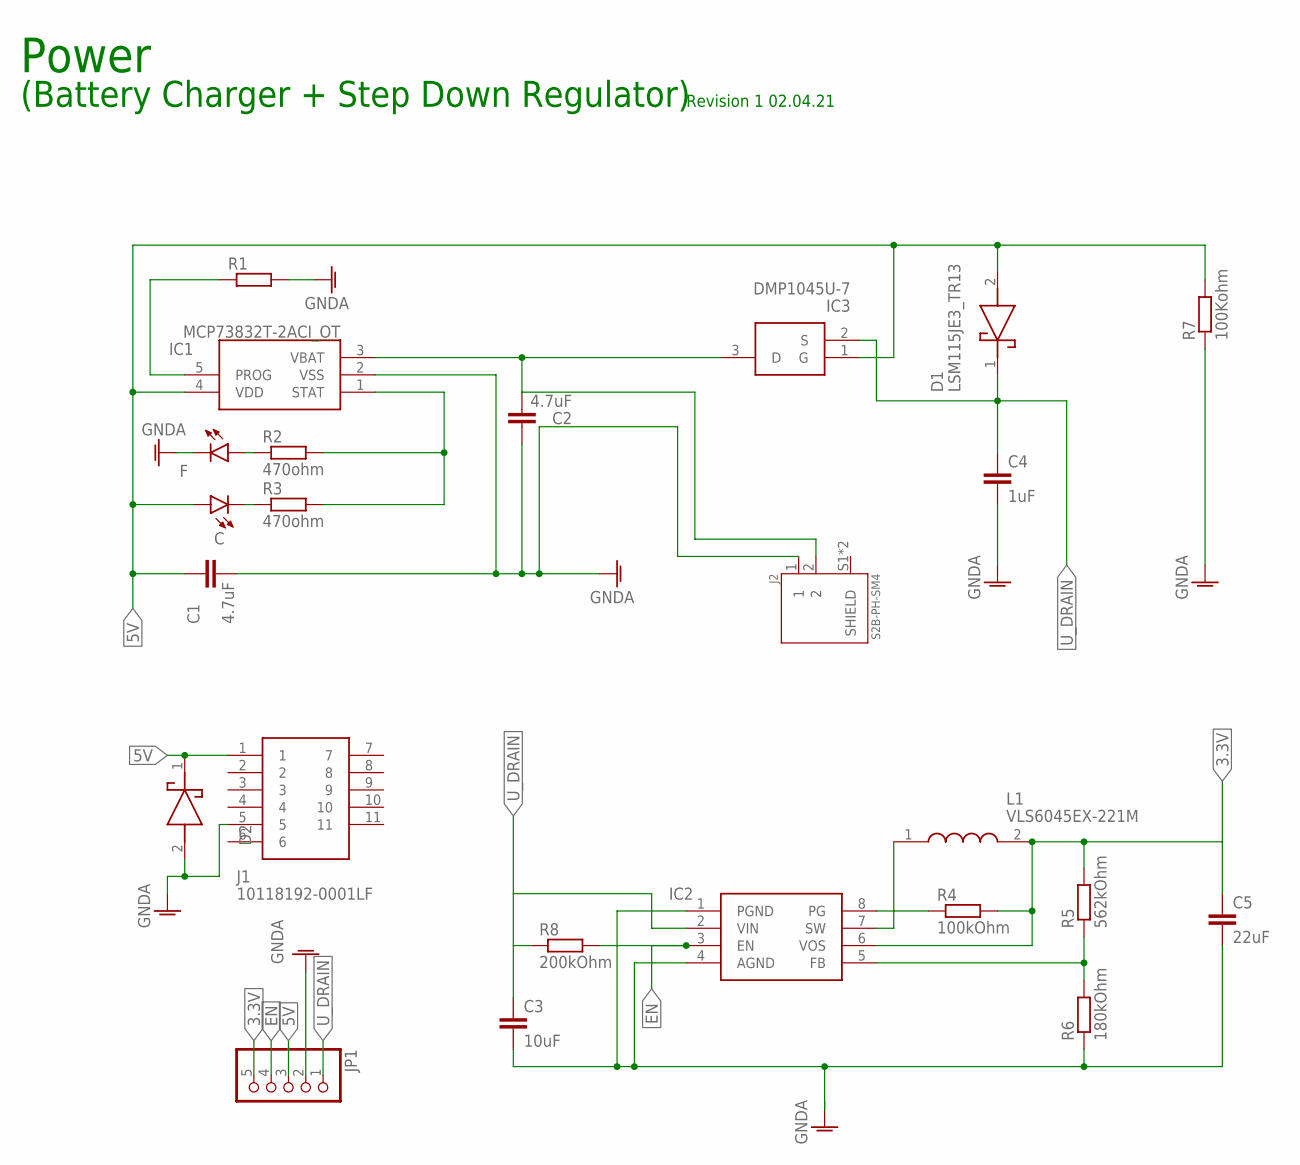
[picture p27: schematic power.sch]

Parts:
C: LED_1206SMT1206; 1206
C1, C2: 4.7uF; C1206
C3: 10uF; C1206
C4: 1uF; C0805
C5: 22uF; C0805K
D1, D2: LSM115JE3_TR13; DIOM5436X330N
F: LED_1206SMT1206; 1206
IC1: MCP73832T-2ACI_OT; SOT95P270X145-5N
IC2: TPS62160DGKR; SOP65P490X110-8N
IC3: DMP1045U-7; SOT96P240X100-3N
J1: 10118192-0001LF; 101181920001LF
J2: S2B-PH-SM4; JST_S2B-PH-SM4-TB(LF)(SN)
JP1: PINHD-1X5; 1X05
L1: VLS6045EX-221M; INDPM6060X450N
R1: R-EU_805R0805; R0805
R2, R3: 470ohm; R0805
R4: 100kOhm; R0805
R5: 562kOhm; R0805
R6: 180kOhm; R0805
R7: 100Kohm; R0805
R8: 200kOhm; R0805

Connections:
3.3V: C5.1, IC2.6 (VOS), JP1.5, L1.2, R4.2, R5.2
5V: C.A, C1.1, D1.2 (A), D2.1 (K), IC1.4 (VDD), IC3.1 (G), J1.1, JP1.3, R7.2
EN: IC2.3 (EN), JP1.4, R8.2
FB: IC2.5 (FB), R5.1, R6.2
GNDA: C1.2, C2.1, C3.2, C4.2, C5.2, D2.2 (A), F.C, IC1.2 (VSS), IC2.1 (PGND), IC2.4 (AGND), J1.5, J2.1, JP1.2, R1.2, R6.1, R7.1
unnamed: IC1.5 (PROG), R1.1
unnamed: F.A, R2.1
unnamed: C.C, R3.1
PG: IC2.8 (PG), R4.1
STAT: IC1.1 (STAT), R2.2, R3.2
SW: IC2.7 (SW), L1.1
U_DRAIN: C3.1, C4.1, D1.1 (K), IC2.2 (VIN), IC3.2 (S), JP1.1, R8.1
VBAT: C2.2, IC1.3 (VBAT), IC3.3 (D), J2.2

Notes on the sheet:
Power
(Battery Charger + Step Down Regulator)
Revision 1 02.04.21

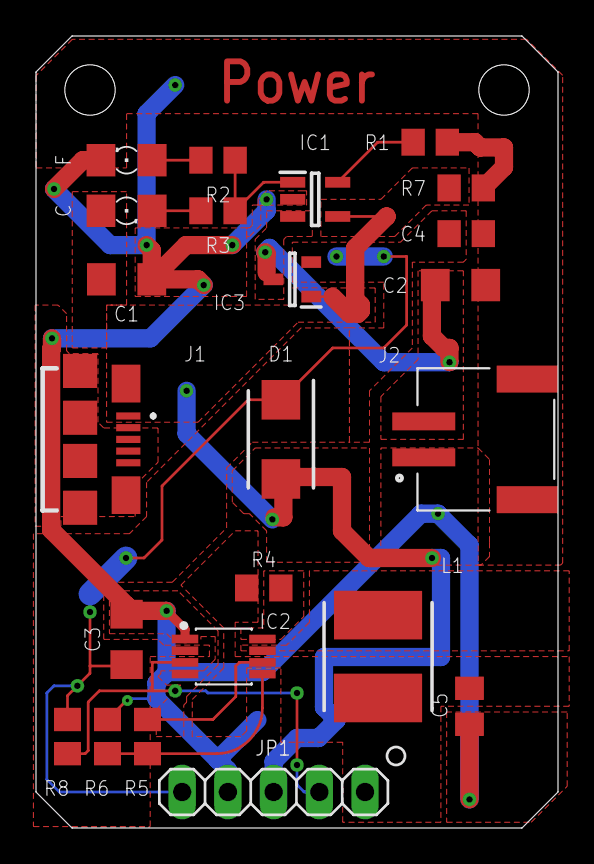
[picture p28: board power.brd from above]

Board: 2 copper layers, 29.0 x 44.0 mm, 24 parts (1 on the bottom side), 13 nets.

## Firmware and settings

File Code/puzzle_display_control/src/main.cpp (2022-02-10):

#include <SoftwareSerial.h>
#include <DFRobotDFPlayerMini.h>
#include "display_setup.h"
#include "display_stuff.h"
#include "login_puzzle.h"
#include "frequency_puzzle.h"
#include "encoder_handle.h"
#include <Puzzle.h>
#include <privateInfo.h>

#include <stdio.h>
#include <stdlib.h>

// Audio interface
#define TX 4
#define RX 15

#define ESA 1      // folder number of Emergency Message
#define Ferdi 2    // folder number of Radio station message
#define goodNews 3 // folder number of good News Radio
#define HIGH_NOISE 10
#define NOISE 10 // folder number of noise
#define LOW_NOISE 10
#define rickroll 99 // default.

#define INIT_VOLUME 8

#define ANTENNA_CORRECT_POS 12

#define MQTT
//#define OPERATORCONTROL

// development mode if we want to leave the idle state without MQTT but with encoder rotation
//#define DEVELOPMENT_MODE

void main_state_machine(void);
bool check_touch_or_encoder_events(void);
bool check_correct_antenna_pos(unsigned int);

tsPoint_t cal_letter;

SoftwareSerial DFPlayerSoftwareSerial(TX, RX);

// Name of Player
DFRobotDFPlayerMini mp3Player;

bool flagset = false;
bool solved = false;

enum GameState
{
    stateIdle = 1,
    stateAntenna,
    stateFrequency,
    stateLogin,
    stateDone,
    stateFinal
};

enum AntennaState
{
    //antenna_NoNoise = 0,
    antenna_Level0 = 10,
    antenna_Level1 = 11,
    antenna_Level2 = 12
};

int enc_num_triggered = 0;

bool ant_correct = false;

int new_vol = 20;
tsPoint_t raw;

// the current state and the next state.
// the next state is only needed if we temporarily need to go back to the state stateAntenna.
// Afterwards, we want to go back to the state we were in before (i.e. the state saved in next_sate)
GameState state;

// the current and the old antenna state (old one is needed for comparison)
AntennaState ant_state;
AntennaState old_ant_state;

// MQTT implementation stuff begins here
StaticJsonDocument<300> doc;
JsonObject JSONencoder = doc.to<JsonObject>();

void setup()
{
    Serial.begin(9600);

    DFPlayerSoftwareSerial.begin(9600);

    mp3Player.begin(DFPlayerSoftwareSerial);
    Serial.println(mp3Player.readFileCounts());

    /* Equalizer: possible values
     *  mp3Player.EQ(DFPlayer_EQ_NORMAL);
     *  mp3Player.EQ(DFPLAYER_EQ_POP);
     *  mp3Player.EQ(DFPLAYER_EQ_ROCK);
     *  mp3Player.EQ(DFPLAYER_EQ_JAZZ);
     *  mp3Player.EQ(DFPLAYER_EQ_CLASSIC);
     *  mp3Player.EQ(DFPLAYER_EQ_BASS);
     */
    mp3Player.EQ(DFPLAYER_EQ_NORMAL);
    // Volume 1 to 30
    mp3Player.volume(INIT_VOLUME);

    mp3Player.stop();

#ifdef MQTT
    /*********************
       WiFi Connection
    *********************/
    Serial.print("Connecting to ");
    Serial.println(SSID);
    // Set name passed to AP while connection
    WiFi.setHostname(NAME);
    // Connect to AP
    WiFi.begin(SSID, PWD);
    // Wait while not connected
    while (WiFi.status() != WL_CONNECTED)
    {
        delay(500);
        Serial.print(".");
    }
    // Print IP
    Serial.println("\nWiFi connected.\nIP Adress: ");
    Serial.println(WiFi.localIP());

    /*********************
         multicast DNS
    *********************/
    // Set name of this device
    if (!MDNS.begin(NAME))
    {
        Serial.println("Setting up MDNS responder!");
    }
    // The service this device hosts (example)
    MDNS.addService("_escape", "_tcp", 2000);

    // OTA setup in separate function
    setupOTA();

    /*************************
         MQTT Setup
    *************************/
    // Set IP and port of broker
    mqtt.setServer(MQTT_SERVER_IP, MQTT_PORT);
    // Set CB function to be called for all subscriptions
    mqtt.setCallback(mqttCallback);
    // Connect to broker using a unique ID (here the name)
    if (mqtt.connect(NAME))
    {
        Serial.println("Connected to MQTT server");
        // Subscribe to a certain topic
        //#TODO: add/put correct Topiclist here
        mqtt.subscribe("3/gamecontrol/#");
        mqtt.subscribe("3/audiocontrol/roomsolved");
    }
    else
    {
        Serial.println("Cannot connect to MQTT server");
    }
#endif

    Serial.println("Hello, RA8875!");
    init_display();
    init_encoder();

    state = stateIdle;

    ant_state = antenna_Level2;
    old_ant_state = antenna_Level2;

#ifdef MQTT
    init_time();
#endif
    // Indicate end of setup
    Serial.println("Setup done!");
}

/**************************************************************************/
/*!
 */
/**************************************************************************/
void loop()
{
#ifdef MQTT
    // Needs to be called to check for external update request
    ArduinoOTA.handle();
    // Checks for MQTT subscriptions
    mqtt.loop();
#endif
    main_state_machine();
}

unsigned int ant_value = 0;

/*
to enable/disable own gamestate-control, it should be sufficient to en/disable the state-statements
this is done with defines
*/
bool secondHint = false;
char sendHint = 1;
unsigned int startTimeMap = 0;
unsigned int startTimeTouch = 0;

void main_state_machine()
{
    static Adafruit_RA8875 local_tft = gettft();
    switch (state)
    {
    case stateIdle:
        if (!flagset)
        {
            mp3Player.stop();

            Serial.print("init idle");
            //local_tft.sleep(true);
            local_tft.graphicsMode();
            fill_display(RA8875_BLACK);
            
            //local_tft.fillRoundRect(0, 0, 100, 180, 10, RA8875_RED);
            local_tft.displayOn(false);
            flagset = true;
        }
        // set antenna encoder to zero.
        encoder_set_value(4, 0);

        #ifdef DEVELOPMENT_MODE
        if (check_game_encoders())
        {
            Serial.print("game encoders turned");
            state = stateAntenna;
            flagset = false;
            local_tft.sleep(false);
            encoder_set_value(1, 0);
            encoder_set_value(2, 0);
            encoder_set_value(3, 0);
        }
        #endif
        break;
    case stateAntenna:
        if (!flagset)
        {
            Serial.println("case 0");
            publish_Hint(1, FIRSTHINT); // release first hint for the antenna game
            mqtt_publish("3/gamecontrol/antenna", "status", "active");
            first_screen();
            check_correct_antenna_pos(ant_value);
            if(ant_value < 10)
            {
                mp3Player.loopFolder(ant_state);
            }
            flagset = true;
        }

        ant_value = check_ant_encoder();
        if (check_correct_antenna_pos(ant_value))
        {
            mp3Player.stop();
            delay(100);

#ifndef OPERATORCONTROL
            state = stateFrequency;
            flagset = false;
#endif

#ifdef MQTT
            mqtt_publish("3/gamecontrol/antenna", "status", "solved"); // send to operator
#endif
        }
        else
        {
            if (ant_state != old_ant_state)
            {
                mp3Player.loopFolder(ant_state);
                old_ant_state = ant_state;
            }
        }
        break;
    case stateFrequency:
        if (!flagset)
        {
            Serial.println("case 1");
            mqtt_publish("3/gamecontrol/map", "status", "active");
            publish_Hint(2, FIRSTHINT); // release first hint for the map/frequency game
            fill_display(BACKGROUND_COLOR);
            encoder_set_value(1, 0);
            encoder_set_value(2, 0);
            encoder_set_value(3, 0);
            init_sliding_bars();
            mp3Player.loopFolder(ESA);

            flagset = true;
            startTimeMap = millis();
        }
        if (check_touch_or_encoder_events())
        {
            solved = sliding_bars(enc_num_triggered, raw, 0);
        }

        if ((millis() - startTimeMap > 120000) && (secondHint == false))
        {
            secondHint = true;
#ifdef MQTT
            publish_Hint(3, SECONDHINT);
#endif
        }

        if (solved)
        {
#ifndef OPERATORCONTROL
            state = stateLogin;
            flagset = false;
#endif
            solved = false;
#ifdef MQTT
            mqtt_publish("3/gamecontrol/map", "status", "solved"); // send to operator
#endif
        }
        break;

    case stateLogin:
        if (!flagset)
        {
            mqtt_publish("3/gamecontrol/touchgame", "status", "active");
            publish_Hint(3, FIRSTHINT); // release first hint for the touchgame
            mp3Player.loopFolder(Ferdi);
            init_rect();
            flagset = true;
            startTimeTouch = millis();
        }

        if (check_touch_or_encoder_events())
        {
            solved = login_game(raw);
        }

#ifdef MQTT
        if ((millis() - startTimeTouch > 120000) && (sendHint == 1))
        { // send second hint after 2 minutes
            sendHint = 2;
            publish_Hint(3, SECONDHINT);
        }
        if ((millis() - startTimeTouch > 240000) && (sendHint == 2))
        { // send third hint after 4 minutes
            sendHint = 3;
            publish_Hint(3, THIRDHINT);
        }
#endif

        if (solved)
        {
#ifndef OPERATORCONTROL
            state = stateDone;
            flagset = false;
#endif
#ifdef MQTT
            mqtt_publish("3/gamecontrol/touchgame", "status", "solved"); // send to operator
            publish_Hint(3, HSOLVED);                                    // send to hintsystem
#endif
        }
        break;

    case stateDone:
        if (!flagset)
        {   fill_display(BACKGROUND_COLOR);
            setup_final_screen();
            flagset = true;
            mp3Player.stop();
        }
        final_screen();
        break;
    case stateFinal:
        if(!flagset){
            flagset = true;
            setup_final_screen();
            mp3Player.disableLoop();
            mp3Player.playFolder(goodNews, 1);
            mp3Player.disableLoopAll();
            mp3Player.volume(21);
            encoder_set_value(5, 21);
            Serial.println("play mp3 again");
        }
        final_screen();
        break;
    }

    // check if volume has been changed (by triggering volume controller)
    if (check_vol_encoder(&new_vol))
    {
        mp3Player.volume(new_vol);
    }

    if (state > stateAntenna && state < stateDone)
    {
        ant_value = check_ant_encoder();

        if (!check_correct_antenna_pos(ant_value))
        {
            flagset = false;
            state = stateAntenna;
        }
    }
}

int last_touched = millis();

bool check_touch_or_encoder_events()
{
    enc_num_triggered = check_game_encoders();

    if (!digitalRead(RA8875_INT) && millis() - last_touched > 500)
    {
        last_touched = millis();
        handleTouchEvent(&raw);
        return true;
    }
    else if (enc_num_triggered)
    {
        set_last_action(enc_num_triggered);
        return true;
    }
    else
    {
        set_last_action(last_action_none);
    }
    return false;
}

bool check_correct_antenna_pos(unsigned int ant_value)
{
    if (ant_value < 4)
    {
        ant_state = antenna_Level2;
    }
    else if (ant_value < 6)
    {
        ant_state = antenna_Level1;
    }
    else if (ant_value < 10)
    {
        ant_state = antenna_Level0;
    }
    else if (ant_value <= ANTENNA_CORRECT_POS)
    {
        // Serial.print("correct");
        return true;
    }
    return false;
}

/*
   Handles incoming data of a stream
   This can be any stream compliant class such as
   Serial, WiFiClient (TCP or UDP), File, etc.
*/
void handleStream(Stream *getter)
{
    // Copy incoming data into msg cstring until newline is received
    snprintf(msg, MSG_SIZE, "%s", getter->readStringUntil('\n').c_str());
    // Some systems also send a carrige return, we want to strip it off
    for (size_t i = 0; i < MSG_SIZE; i++)
    {
        if (msg[i] == '\r')
        {
            msg[i] = '\0';
            break;
        }
    }
    // Handle given Msg
    const char *returnMsg = handleMsg(msg, msg); // not sure what happens here,
    // Write something back to stream only if wanted
    if (returnMsg[0] != '\0')
    {
        getter->println(returnMsg);
    }
}

/*
   Handle a received message, may return some answer.
*/
const char *handleMsg(const char *msg, const char *topic)
{
    // strcmp returns zero on a match
    if ((strcmp(topic, "3/gamecontrol/final") == 0) && (strcmp(msg, "solved") == 0))
    {
        // puzzleSolved();
        state = stateDone;
        flagset = false;
    }
    else if ((strcmp(topic, "3/gamecontrol/antenna") == 0) && (strcmp(msg, "off") == 0))
    {
        // puzzleIdle(); //maybe different idle state required
        //flagset = false;
        //state = stateIdle;
        Serial.println("Idle");
    }
    else if ((strcmp(topic, "3/gamecontrol/antenna") == 0) && (strcmp(msg, "on") == 0))
    {
        if(state != stateAntenna){
            flagset = false;
            state = stateAntenna;
            Serial.println("Antenna");
        }
    }
    else if ((strcmp(topic, "3/gamecontrol/map") == 0) && (strcmp(msg, "off") == 0))
    {
        // puzzleIdle(); //maybe different idle state required
        //flagset = false;
        //state = stateIdle;
    }
    else if ((strcmp(topic, "3/gamecontrol/map") == 0) && (strcmp(msg, "on") == 0))
    {
        if(state != stateFrequency){
            Serial.println("Map");
            flagset = false;
            state = stateFrequency;
            ant_value = ANTENNA_CORRECT_POS;
            encoder_set_value(4, ANTENNA_CORRECT_POS);
        }
    }
    else if ((strcmp(topic, "3/gamecontrol/touchgame") == 0) && (strcmp(msg, "off") == 0))
    {
        // puzzleIdle(); //maybe different idle state required
        //flagset = false;
        //state = stateIdle;
    }
    else if ((strcmp(topic, "3/gamecontrol/touchgame") == 0) && (strcmp(msg, "on") == 0))
    {
        if(state != stateLogin){
            flagset = false;
            state = stateLogin;
            ant_value = ANTENNA_CORRECT_POS;
            encoder_set_value(4, ANTENNA_CORRECT_POS);
            set_solved_frequency(1332);
            Serial.println("Touch");
        }
    }
    else if (strcmp(msg, "idle") == 0)
    {
        // puzzleIdle();
        flagset = false;
        state = stateIdle;
    }
    else if ((strcmp(topic, "3/audiocontrol/roomsolved") == 0) && (strcmp(msg, "on") == 0))
    {
        if(state != stateFinal){
            flagset = false;
            state = stateFinal;
            Serial.println("FinalMessage");
        }
    }
    else
    {
        return "Unknown command";
    }
    return "";
}

/*
   Setup OTA Updates
*/
void setupOTA()
{
    // Set name of this device (again)
    ArduinoOTA.setHostname(NAME);
    // Set a password to protect against uploads from other parties
    ArduinoOTA.setPassword(OTA_PWD);

    // CB function for when update starts
    ArduinoOTA.onStart([]()
                       { Serial.println("Start updating"); });
    // CB function for when update starts
    ArduinoOTA.onEnd([]()
                     { Serial.println("Finished updating"); });
    // CB function for progress
    ArduinoOTA.onProgress([](unsigned int progress, unsigned int total)
                          { Serial.printf("Update at %u % \n", progress / (total / 100)); });
    // CB function for when update was interrupted
    ArduinoOTA.onError([](ota_error_t error)
                       {
    Serial.println("Error updating");
    ESP.restart(); });
    // Start OTA update service
    ArduinoOTA.begin();
}

/*
 * Callback for MQTT messages on subscribed topics
 */
void mqttCallback(char *topic, byte *message, unsigned int length)
{
    // Convert message as byte array to cstring
    unsigned int len = min((int)length, (int)(MSG_SIZE - 1));
    memcpy(&msg[0], message, len);
    msg[len] = '\0';
    // Print over serial
    Serial.printf("MQTT msg on topic: %s: %s\n", topic, &msg);

    // Try to deserialize the JSON msg
    DeserializationError error = deserializeJson(dict, msg);
    // Test if parsing succeeds.
    if (error)
    {
        Serial.println("error deserializing the msg");
    }
    else
    {
        Serial.println("Msg is of valid JSON format");
        // Try to extract new state
        const char *newState = dict["state"];
        // If key exists this is not NULL
        Serial.println(newState);
        if (newState)
        {
            handleMsg(newState, topic);
        }
    }
}

void mqtt_publish(const char *topic, const char *method, const char *state)
{
    JSONencoder["method"] = method;
    JSONencoder["state"] = state;
    JSONencoder["data"] = 0;

    char JSONmessageBuffer[100];

    serializeJson(doc, JSONmessageBuffer, 100);
    mqtt.publish(topic, JSONmessageBuffer, true); //"test", retained);
}

void publish_Hint(int game, int hintcount)
{
    const char hintTopic[] = "game/puzzle3";
    switch (game)
    {
    case 1:
        if (hintcount == FIRSTHINT)
        {
            Serial.print("sending hint 1");
            mqtt.publish(hintTopic, "antenna_activate_1", true);
        }
        break;
    case 2:
        if (hintcount == FIRSTHINT)
        {
            Serial.print("sending hint 1");
            mqtt.publish(hintTopic, "map_activate_1", true);
        }
        else if (hintcount == SECONDHINT)
        {
            Serial.print("sending hint 1");
            mqtt.publish(hintTopic, "map_activate_2", true);
        }
        break;
    case 3:
        if (hintcount == FIRSTHINT)
        {
            mqtt.publish(hintTopic, "touch_activate_1", true);
        }
        else if (hintcount == SECONDHINT)
        {
            mqtt.publish(hintTopic, "touch_activate_2", true);
        }
        else if (hintcount == THIRDHINT)
        {
            mqtt.publish(hintTopic, "touch_activate_3", true);
        }
        else if (hintcount == HSOLVED)
        {
            mqtt.publish(hintTopic, "S");
        }
        break;
    default:
        break;
    }
}

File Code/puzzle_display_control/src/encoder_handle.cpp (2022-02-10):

#include "encoder_handle.h"
#include <ESP32Encoder.h>

class Encoders {
    public:
        ESP32Encoder _encoder;
        int encoder_value;
        int old_value;
};

Encoders encoder[NUM_ENCODERS_DEFINED];

Encoders encoder_vol;

Encoders encoder_ant;

void init_encoder()
{

    ESP32Encoder::useInternalWeakPullResistors=UP;

    

	// use pin 19 and 18 for the first encoder
	encoder[0]._encoder.attachSingleEdge(32, 33);
    encoder[0]._encoder.setFilter(1023);
	// use pin 17 and 16 for the second encoder
	
    if(NUM_ENCODERS_DEFINED > 1)
    {
        encoder[1]._encoder.attachSingleEdge(26, 25);
        encoder[1]._encoder.setFilter(1023);
    }
    if(NUM_ENCODERS_DEFINED > 2)
    {
        encoder[2]._encoder.attachSingleEdge(17, 16);
        encoder[2]._encoder.setFilter(1023);
    }
		
    int i;
    for(i = 0; i<NUM_ENCODERS_DEFINED; i++)
    {
        // set starting count value after attaching
        encoder[i]._encoder.setCount(0);

        // clear the encoder's raw count and set the tracked count to zero
        //encoder2.clearCount();
        encoder[i].encoder_value = 0;
        encoder[i].old_value = 0;
        Serial.println("Encoder Start = " + String((int32_t)encoder[0]._encoder.getCount()));

    }
    /*
    encoder[0]._encoder.setFilter(1000);
    encoder[1]._encoder.setFilter(1000);
    encoder[2]._encoder.setFilter(1000);
*/

    // init volume encoder
    encoder_ant._encoder.attachSingleEdge(34, 35);
    encoder_ant._encoder.setFilter(1023);

    // set starting count value after attaching
    encoder_ant._encoder.setCount(0);

    // clear the encoder's raw count and set the tracked count to zero
    //encoder2.clearCount();
    encoder_ant.encoder_value = 0;
    encoder_ant.old_value = 0;



    // init volume encoder
    encoder_vol._encoder.attachSingleEdge(21, 22);
    encoder_vol._encoder.setFilter(1023);

    // set starting count value after attaching
    encoder_vol._encoder.setCount(8);

    // clear the encoder's raw count and set the tracked count to zero
    //encoder2.clearCount();
    encoder_vol.encoder_value = 0;
    encoder_vol.old_value = 0;
}

int old_val = 0;

/***********************************************************************
* This function checks if any of the game encoders (the encoders on the top)
* have been triggered and if yes, it saves the new value and 
* returns the corresponding encoder number 
***********************************************************************/
int check_game_encoders()
{
    int i;
    for(i = 0; i<NUM_ENCODERS_DEFINED; i++)
    {
        if (encoder[i].encoder_value !=  encoder[i]._encoder.getCount())
        {
            if(encoder[i]._encoder.getCount() >= -12 && encoder[i]._encoder.getCount() <= 12)
            {
                encoder[i].encoder_value = encoder[i]._encoder.getCount();
                Serial.println("Encoder no " + String(i) + ", count  = " + String((int32_t)encoder[i].encoder_value));
            }
            else
            {
                encoder[i]._encoder.setCount(encoder[i].encoder_value);
            }
            return (i+1);       
        }
    }
    return 0;
}

/***********************************************************************
* This function checks if the volume encoder (the encoder on the side)
* has been triggered and if yes, it saves the new value, sets the ne_volume 
* variable accordingly and returns true
***********************************************************************/
bool check_vol_encoder(int* new_volume)
{
    if (encoder_vol.encoder_value !=  encoder_vol._encoder.getCount())
        {
            if(encoder_vol._encoder.getCount() >= 0 && encoder_vol._encoder.getCount() < 26)
            {
                encoder_vol.encoder_value = encoder_vol._encoder.getCount();
                Serial.println("Encoder vol count  = " + String((int32_t)encoder_vol.encoder_value));
                *new_volume = encoder_vol.encoder_value;
            }
            else
            {
                encoder_vol._encoder.setCount(encoder_vol.encoder_value);
            }
            return true;       
        }
    return false;
}

/***********************************************************************
* This function checks if the antenna encoder (the encoder inside the radio)
* has been triggered and if yes, it makes sure that the value is always between 
* -12 and 12, it saves the new value and returns an unsigned 
* version of the value, which is between 0 and 12.
***********************************************************************/
unsigned int check_ant_encoder()
{
    int ant_value;
    if (encoder_ant.encoder_value !=  encoder_ant._encoder.getCount())
        {
            if(encoder_ant._encoder.getCount() > -12 && encoder_ant._encoder.getCount() <= 12)
            {
                encoder_ant.encoder_value = encoder_ant._encoder.getCount();
                
                Serial.println("Encoder ant count  = " + String((int32_t)encoder_ant.encoder_value));
            }
            else if(encoder_ant._encoder.getCount() <= -12)
            {
                encoder_ant._encoder.setCount(abs(encoder_ant._encoder.getCount())-2);
                encoder_ant.encoder_value = encoder_ant._encoder.getCount();
            }        
            else if(encoder_ant._encoder.getCount() > 12)
            {
                encoder_ant._encoder.setCount(-(encoder_ant._encoder.getCount())+2);
                encoder_ant.encoder_value = encoder_ant._encoder.getCount();
            }
        }

    ant_value = abs(encoder_ant.encoder_value);
    return ant_value;
}

/***********************************************************************
* returns the saved value of the corresponding encoder
***********************************************************************/
int encoder_get_value(int encoder_num)
{
    if(encoder_num <= NUM_ENCODERS_DEFINED && encoder_num > 0)
    {
        return encoder[encoder_num-1].encoder_value;
    }   
    return -1;
}

/***********************************************************************
* sets the saved value of the corresponding encoder
***********************************************************************/
void encoder_set_value(int encoder_num, int value)
{
    if(encoder_num <= NUM_ENCODERS_DEFINED && encoder_num > 0)
    {
        Serial.print(value);
        encoder[encoder_num-1].encoder_value = value; 
        encoder[encoder_num-1]._encoder.setCount(encoder[encoder_num-1].encoder_value);
    }
    else if(encoder_num == 4)
    {
        // encoder 4 is the antenna controller
        encoder_ant.encoder_value = value;
        encoder_ant._encoder.setCount(encoder_ant.encoder_value);
    }
    else if(encoder_num == 5)
    {
        // encoder 5 is the volume controller
        encoder_vol.encoder_value = value;
        encoder_vol._encoder.setCount(encoder_vol.encoder_value);
    }
}

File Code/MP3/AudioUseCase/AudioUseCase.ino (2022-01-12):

#include <ESPmDNS.h>
#include <SoftwareSerial.h>
#include <DFRobotDFPlayerMini.h>
#include <ESP32Encoder.h>


#define TX 22 
#define RX 23 

#define ESA 1       // folder number of Emergency Message
#define Ferdi 2     // folder number of Radio station message 
#define goodNews 3  // folder number of good News Radio
// RX/TX port definition

void setupTest();
void statusChange();
void volumeControl();

ESP32Encoder volume;

// Init Encoder for Volume control
volume._encoder.attachHalfQuad(32, 33);
volume._encoder.setCount(0);

Serial.println("Encoder Start = " + String((int32_t)volume._encoder.getCount()));


int state = 0;   // is to be updated if gamestate changes
SoftwareSerial DFPlayerSoftwareSerial(TX, RX);

// Name of Player
DFRobotDFPlayerMini mp3Player;

void setup(){
  DFPlayerSoftwareSerial.begin(9600);
  Serial.begin(9600);

  mp3Player.begin(DFPlayerSoftwareSerial);
  Serial.println(mp3Player.readFileCounts());
  
  /* Equalizer: possible values
   *  mp3Player.EQ(DFPlayer_EQ_NORMAL);
   *  mp3Player.EQ(DFPLAYER_EQ_POP);
   *  mp3Player.EQ(DFPLAYER_EQ_ROCK);
   *  mp3Player.EQ(DFPLAYER_EQ_JAZZ);
   *  mp3Player.EQ(DFPLAYER_EQ_CLASSIC);
   *  mp3Player.EQ(DFPLAYER_EQ_BASS);
  */
  mp3Player.EQ(DFPLAYER_EQ_NORMAL);
  // Volume 1 to 30
  mp3Player.volume(15);

  int enc = 0;

}

void loop(){
  state = 0;
  statusChange(state);  
}





//___________Function Definitions______________

void statusChange(int state){
    switch (state){
      case 0:
              setupTest();
              state = 10;
              break;
      case 1:
              //play ESA Broadcast
              mp3Player.loopFolder(ESA);
              state = 10;
              break;
      case 2:
              //play Ferdi Radio
              mp3Player.loopFolder(Ferdi);
              state = 10;
              break;
      case 3: 
              //play Happy Radio
              mp3Player.loopFolder(goodNews);
              state = 10;
              break;
      case 10:
              //playback as it is, waiting for new state update
              break;
      default: 
              break;             
  }
}

void volumeControl(){
  
}


void setupTest(){
   // detect number of files in folder and show
    int numberFiles = mp3Player.readFileCountsInFolder(ESA);
  
    // if no files are in the folder
    if (numberFiles == -1){
      Serial.println("Folder doesn't contain any music files!");  
      Serial.println("Closing the Program!");
      while(1);
    } else {
      Serial.print(String(numberFiles) + " Dateien im Ordner " + String(ESA));
      mp3Player.loopFolder(ESA);
    }
}

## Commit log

2021-11-10 added yesterday's notes. Details about our puzzle and a first, rough BOM
2021-11-11 updated BOM
2021-12-01 added eagle files
    [mainboard.sch, power.brd, power.sch]
2021-12-03 changed schematic for display in eagle
    [mainboard.sch]
2021-12-07 Minimum touchscreen demo with calibration.
2021-12-07 added the first code for the Audio and more Datasheets of ESP32
2021-12-08 added EEPROM support and included encoder.
2021-12-09 added first steps for encoder handling and sliding bars
2021-12-09 updated mainboard schematic
    [mainboard.sch]
2021-12-13 added Library for DFPlayerMini
    [mainboard.sch]
2021-12-13 added DFPlayer to mainboard schematic
    [mainboard.sch]
2021-12-16 uploaded stl of PinHead-EncoderKnob
    [EncoderPinHead.stl]
2022-01-07 added all 3DModels and slice examples
    [Antenna v5.stl, Display_housing_BUTTOM.stl, Display_housing_TOP.stl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]
2022-01-07 delted 3D-Model
    [RadioFoot.stl]
2022-01-09 Added Puzzle-Control/MQTT Prototype
2022-01-11 added first screen. but noise not nice yet
    [display_setup.cpp, display_stuff.cpp, main.cpp]
2022-01-12 added first screen (noise). Screen is removed by encoder event until we have a working antenna
    [display_stuff.cpp, main.cpp]
2022-01-12 added usage of a second encoder, general settings
2022-01-13 some changes and fixed bug in set_encoder_handle function
    [encoder_handle.cpp]
2022-01-13 added 3rd encoder
2022-01-16 removed a few bugs and added goal stage for rectangle puzzle
    [display_stuff.cpp]
2022-01-16 removed bug in random number generation
    [display_stuff.cpp]
2022-01-17 added show button, removed encoder3 function. This is done with show button now instead
2022-01-17 added show button label: now show button can be pressed up tp 3 times, afterwards the game is reset
    [display_stuff.cpp]
2022-01-17 added title of rectangle game, changed direction of rectangle movements with encoder trigger
2022-01-17 added additional encoders and connected them to the ESP
    [mainboard.sch]
2022-01-19 updated and added 3D print files
    [Antenna.stl, DisplayHousingButtom.stl, DisplayHousingTop.stl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]
2022-01-19 added Lasercut files
    [antennaSupport.dxf, leftPlate.dxf, rightPlate.dxf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]
2022-01-19 deleted outdated files
    [Antenna v5.stl, Display_housing_BUTTOM.stl, EncoderHead v8.stl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]
2022-01-19 changed directory name
    [Antenna.stl, DisplayHousingButtom.stl, DisplayHousingTop.stl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]
2022-01-19 added 3D model of Radio
    [EC11 Rotary Encoder Dode Switch-15mm .STEP, REAL-Usb 5pin Board.SLDPRT, REAL-Usb 5pin Board.STEP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]
2022-01-19 Display circuit mount test
    [DisplayCircuitMount.stl]
2022-01-20 added volume control encoder and functioning
2022-01-21 update manufacturing file
    [Adafruit RA8875 TFT Breakout.brd, Adafruit RA8875 TFT Breakout.sch, DisplayHousingTop.stl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]
2022-01-23 added reset button
2022-01-23 fixed volume change bug
    [display_stuff.cpp, encoder_handle.cpp, main.cpp]
2022-01-26 added audio, new test print stl.
    [smallTestPrint.stl]
2022-01-26 new smallTestprint
    [smallTestPrint.stl]
2022-01-26 added 3D print antenna Support file
    [antennaSupport_3Dprint.stl]
2022-01-26 new antenna support
    [antennaSupport_3Dprint.stl]
2022-01-26 other versions
    [antennaSupport_3DprintV2.stl, antennaSupport_3Dprint_v1.stl]
2022-01-26 antenna support v3
    [antennaSupport_3DprintV3.stl]
2022-01-27 many changes, including frequency display und select button for game 1, and letter removal for game 2
2022-01-27 nicer select button, no reset after selecting frequency, error msg
    [display_stuff.cpp]
2022-01-27 removed bug for removing letters at first action.
    [display_stuff.cpp]
2022-01-31 some random changes, e.g. with antenna, still in progress
2022-01-31 updated TopDisplayHpusing
    [DisplayHousingTop.stl]
2022-01-31 new Antenna
    [Antenna.stl]
2022-01-31 Antenna update
    [Antenna.stl, topPlate_3DPrint.stl]
2022-01-31 outsourced functions in two new c++ files for better overview. Added states for antenna positions
2022-01-31 completed antenna position checker
2022-01-31 hopefully almost removed the bug with the triangle in the frequency game
    [display_stuff.cpp, frequency_puzzle.cpp, main.cpp]
2022-01-31 removed bug for removing letters, workaround
    [login_puzzle.cpp, main.cpp]
2022-02-01 included cursor with 3rd encoder
2022-02-03 removed a few more bugs
    [display_stuff.cpp, encoder_handle.cpp, frequency_puzzle.cpp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]
2022-02-03 corrected mistake in MQTT message
    [main.cpp]
2022-02-03 added encoder filters
2022-02-07 Revert "changed hint-system according to provided requirements"
    This reverts commit 95b610a824ab029964c2c20212dc70f59835ce79.
    [main.cpp]
2022-02-07 removed tcp server connection to make current time getter work. Also restructured some stuff in relation to the time getter
2022-02-07 bug fix: correct hour display
    [display_stuff.cpp]
2022-02-07 added development mode: usually idle state can only go to antenna state by Operator via MQTT. But in development mode, we can use the encoders for this
2022-02-08 small bug fixes: hint system and clock in done state
    [display_stuff.cpp, encoder_handle.cpp, main.cpp]
2022-02-10 some more bug fixes
    [display_stuff.cpp, encoder_handle.cpp, frequency_puzzle.cpp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]
2022-02-10 bug fix: display is black in idle mode now.
    [display_setup.cpp, display_stuff.cpp, frequency_puzzle.cpp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]
2022-02-10 fixed volume bug final state
    [display_stuff.cpp, main.cpp]

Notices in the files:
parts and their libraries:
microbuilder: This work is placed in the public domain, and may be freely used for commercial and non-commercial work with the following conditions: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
